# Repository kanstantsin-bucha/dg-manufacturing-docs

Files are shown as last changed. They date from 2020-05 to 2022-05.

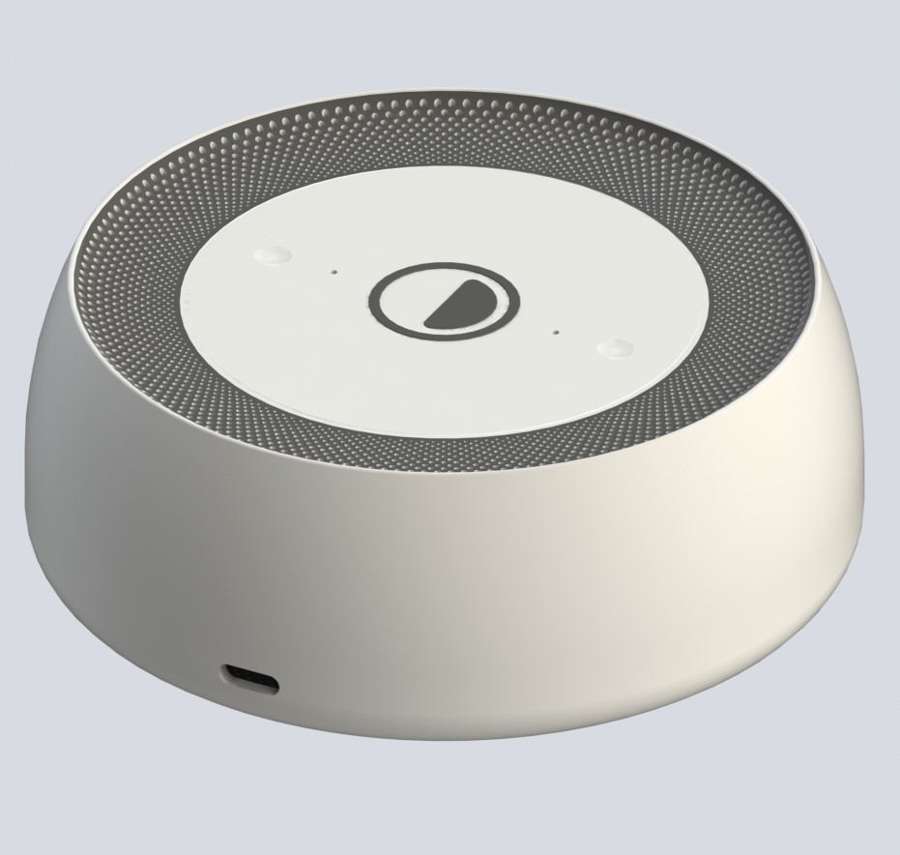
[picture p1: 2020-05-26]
housing/enclosure/DAir-Lily/Preview/2_.jpg

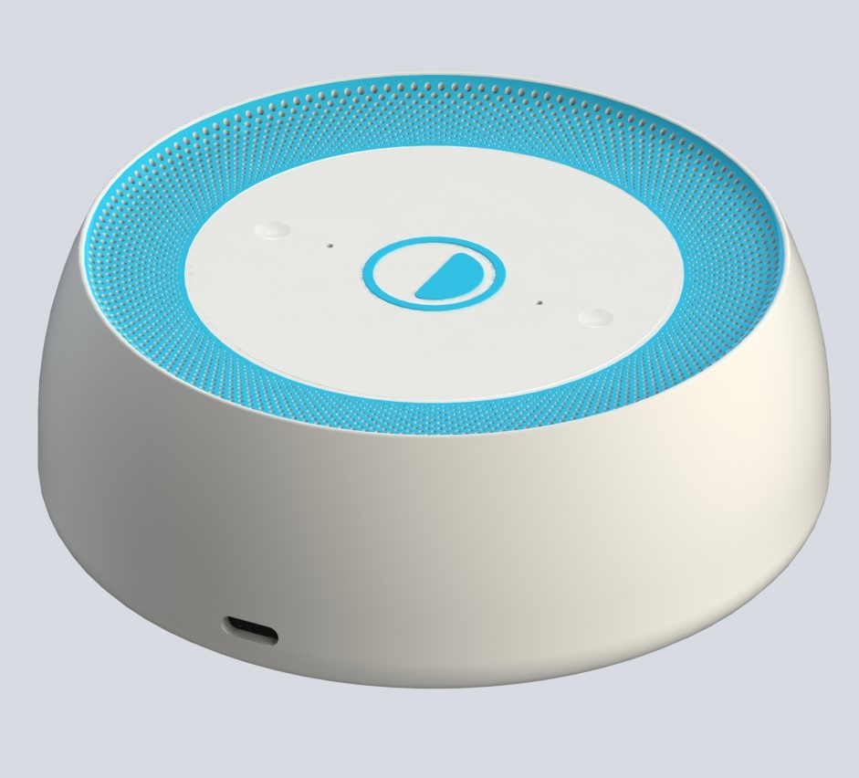
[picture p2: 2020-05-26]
housing/enclosure/DAir-Lily/Preview/1_.jpg

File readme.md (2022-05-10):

## Commit style 

123 - Title of the task

* Description of change that were introduced in commit 
* Same here

## Naming Style

* We use only characters from base table (english) to name the files and directories in repo

----

# This is repo for docs related to manufacturing the Detecta Group first smart portable gas detector

# MVP

* Currrent MVP is D-Air Aster in the chinese housing. The latest board version is 0.0.0.4

* We stop our development of the housing because it is too cost inaffective.
We should use housing from the 3-rd party.

# Table of directories

## electric - all related to circuit part of the Thing

*  circuit - Schematic of electric part of the Thing

## housing - all related to development of the housing

> D-Fire (Detecta Plug-in) - model housing with Plug-in

> D-Fire (Detecta microUSB) - model housing with microUSB

> D-Fire (OKW) - model housing OKW

> Model - models of the housing and parts made in Solidworks

> Models for 3D printing - models STL and STEP formats

> Doc - Drawings

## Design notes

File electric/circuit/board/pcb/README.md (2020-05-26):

# Versioning:

X.Y.Z

----

* Letter X means type of housing:

0 - portable housing with charger function

1 - OKW housing

2 - Detecta housing with/without plug or usb

----

* Letter Y means version of circuit:

1 - old version for portable housing with charger function

2 - current circuit version

3,4,5,... - future circuits

----

* Letter Z means different fixes. For example overlay fixing or litle other components layout

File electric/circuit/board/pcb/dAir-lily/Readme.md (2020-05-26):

# Versions

- [x] Pretest

# Notes

main-bottom --- test layout where all main components are on the bottom pcb, buttons and leds on the top pcb, ME2-CO is looking down

main-top --- test lay

out where all components are on the top pcb, on the bottom pcb only power supply components, ME2-CO is looking up

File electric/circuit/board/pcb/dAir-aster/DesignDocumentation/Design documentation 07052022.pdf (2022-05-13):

Формат А4 Инв.№подл. Взам.инв.№ Инв.№дубл. Подп. и дата Подп. и дата Спарв. № Перв. примен.

Н.контр. | Фамилия
Утв. | Фаимлия
| Лист
Разраб. | Фамилия | | | Спецификация | Лит. | Лист | Листов
| | Пров. | Фамилия
| | Т.контр.
Изм. | № докум. | Подпись | Дата Формат Зона Поз. | Обозначение | Наименование | Кол. | Приме-

## чание

Документация

А | 1 | 2 Устройство хххххх

## АБВГД.3.003.000

А3 | АБВГД.3.003.000 СБ | Сборочный чертёж
А2 | АБВГД.3.003.000 Э3 | Схема электрическая
| | принципиальная
А4 | АБВГД.3.003.000 ПЭ | Перечень элементов
А4 | ТУ BY 000000000.003-2021-ТУ | Технические условия
А4 | АБВГД.3.003.000 РЭ | Руководство по эксплуатации

Сборочные единицы

А2 | АБВГД.3.003.101 СБ | Плата

Детали

А3 | 2 | АБВГД.3.003.001 | Основание | 1
А3 | 3 | АБВГД.3.003.002 | Крышка | 1

1

Формат А4 Инв.№подл. Взам.инв.№ Инв.№дубл. Подп. и дата Подп. и дата Спарв. № Перв. примен. | Формат Зона | Поз. | Обозначение | Наименование | Кол. | Приме-

чание

Копировал

Изм.Лист | № докум. | Подпись | Дата

Стр.

## 2 АБВГД.3.003.000

Стандартные изделия

4 | Винт М2×5 | 4

Формат А2 Инв.№подл. Взам.инв.№ Инв.№дубл. Подп. и дата Подп. и дата Спарв. № Перв. примен.

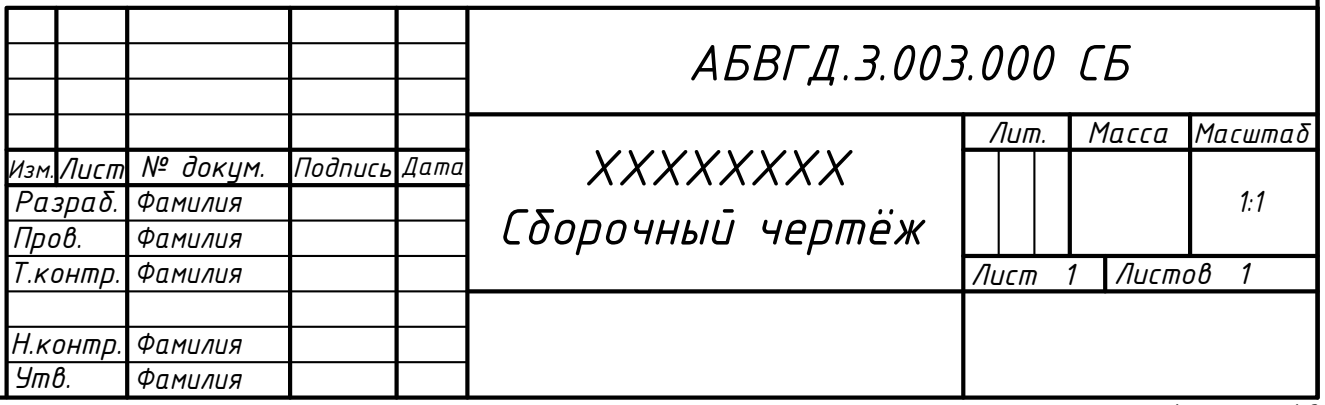
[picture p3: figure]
Лист Разраб. Пров.; № докум.; Листов 1; Лит.; Лист 1; Масса; Изм.; Подпись; Дата; Масштаб; АБВГД.3.003.000 СБ; XXXXXXXX Сборочный чертёж

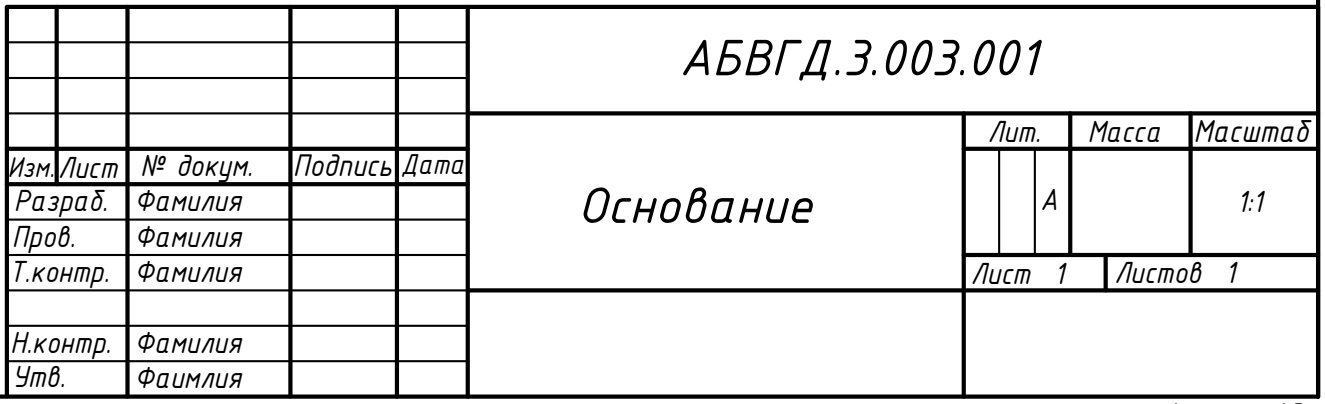
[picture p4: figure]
Лист Разраб. Пров.; № докум.; Листов 1; Лит.; Лист 1; Масса; Изм.; Подпись; Дата; Масштаб А; Фамилия; Фаимлия; Основание; АБВГД.3.003.001

Формат А3

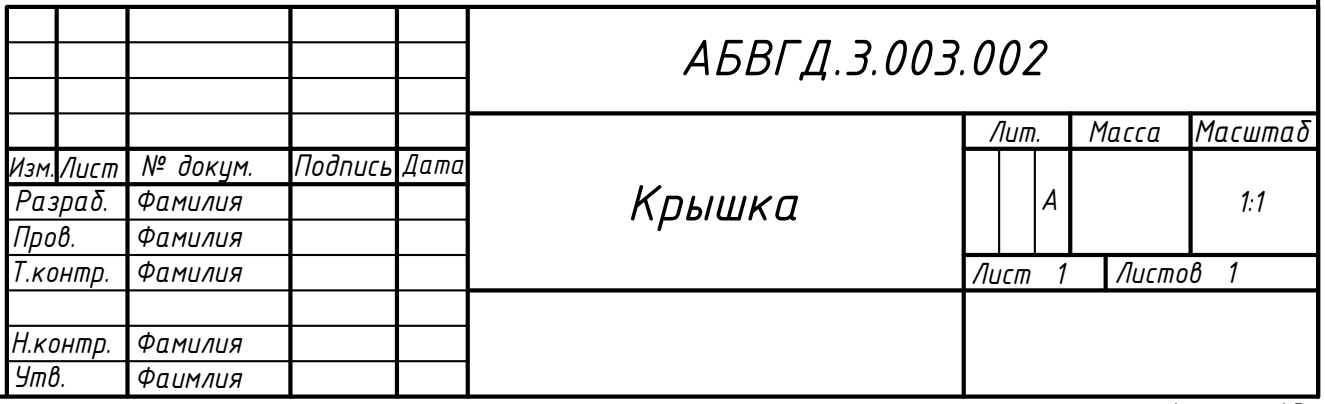
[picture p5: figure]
Лист Разраб. Пров.; № докум.; Листов 1; Лит.; Лист 1; Масса; Изм.; Подпись; Дата; Масштаб А; Фамилия; Фаимлия; Крышка; АБВГД.3.003.002

Формат А3

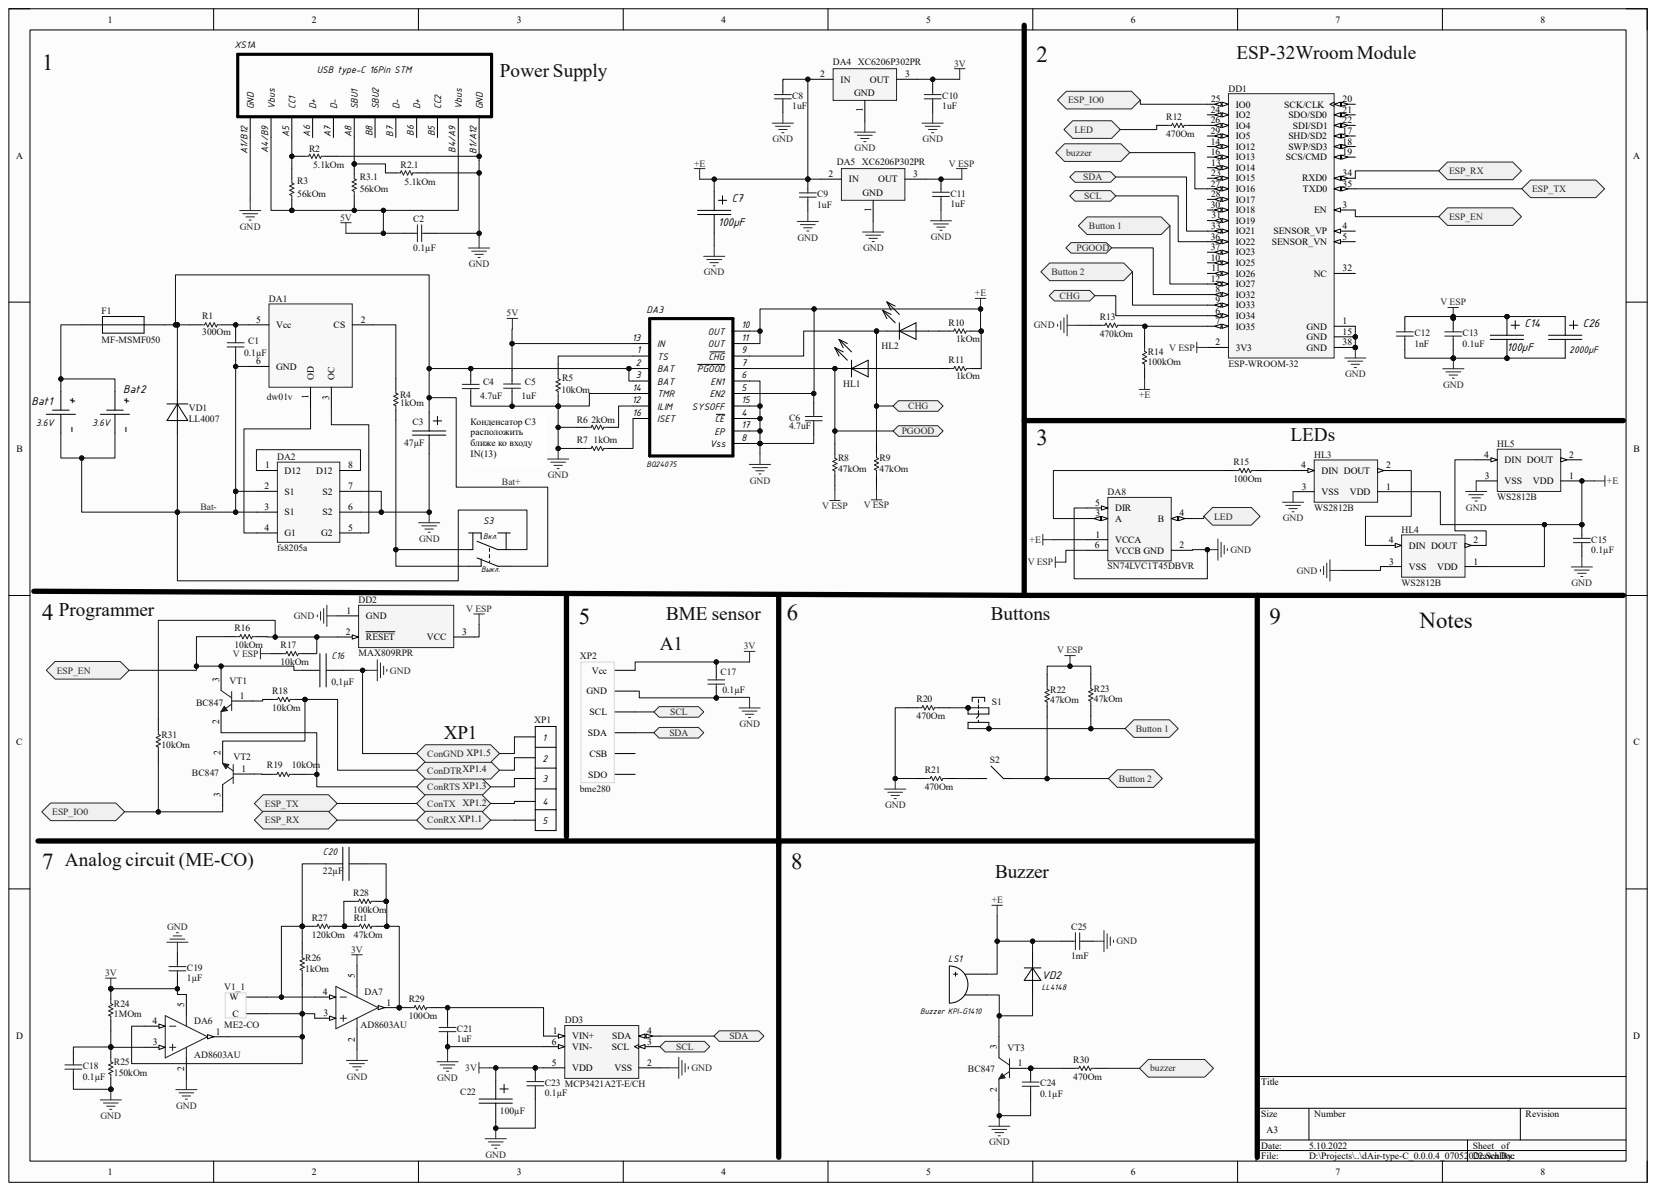
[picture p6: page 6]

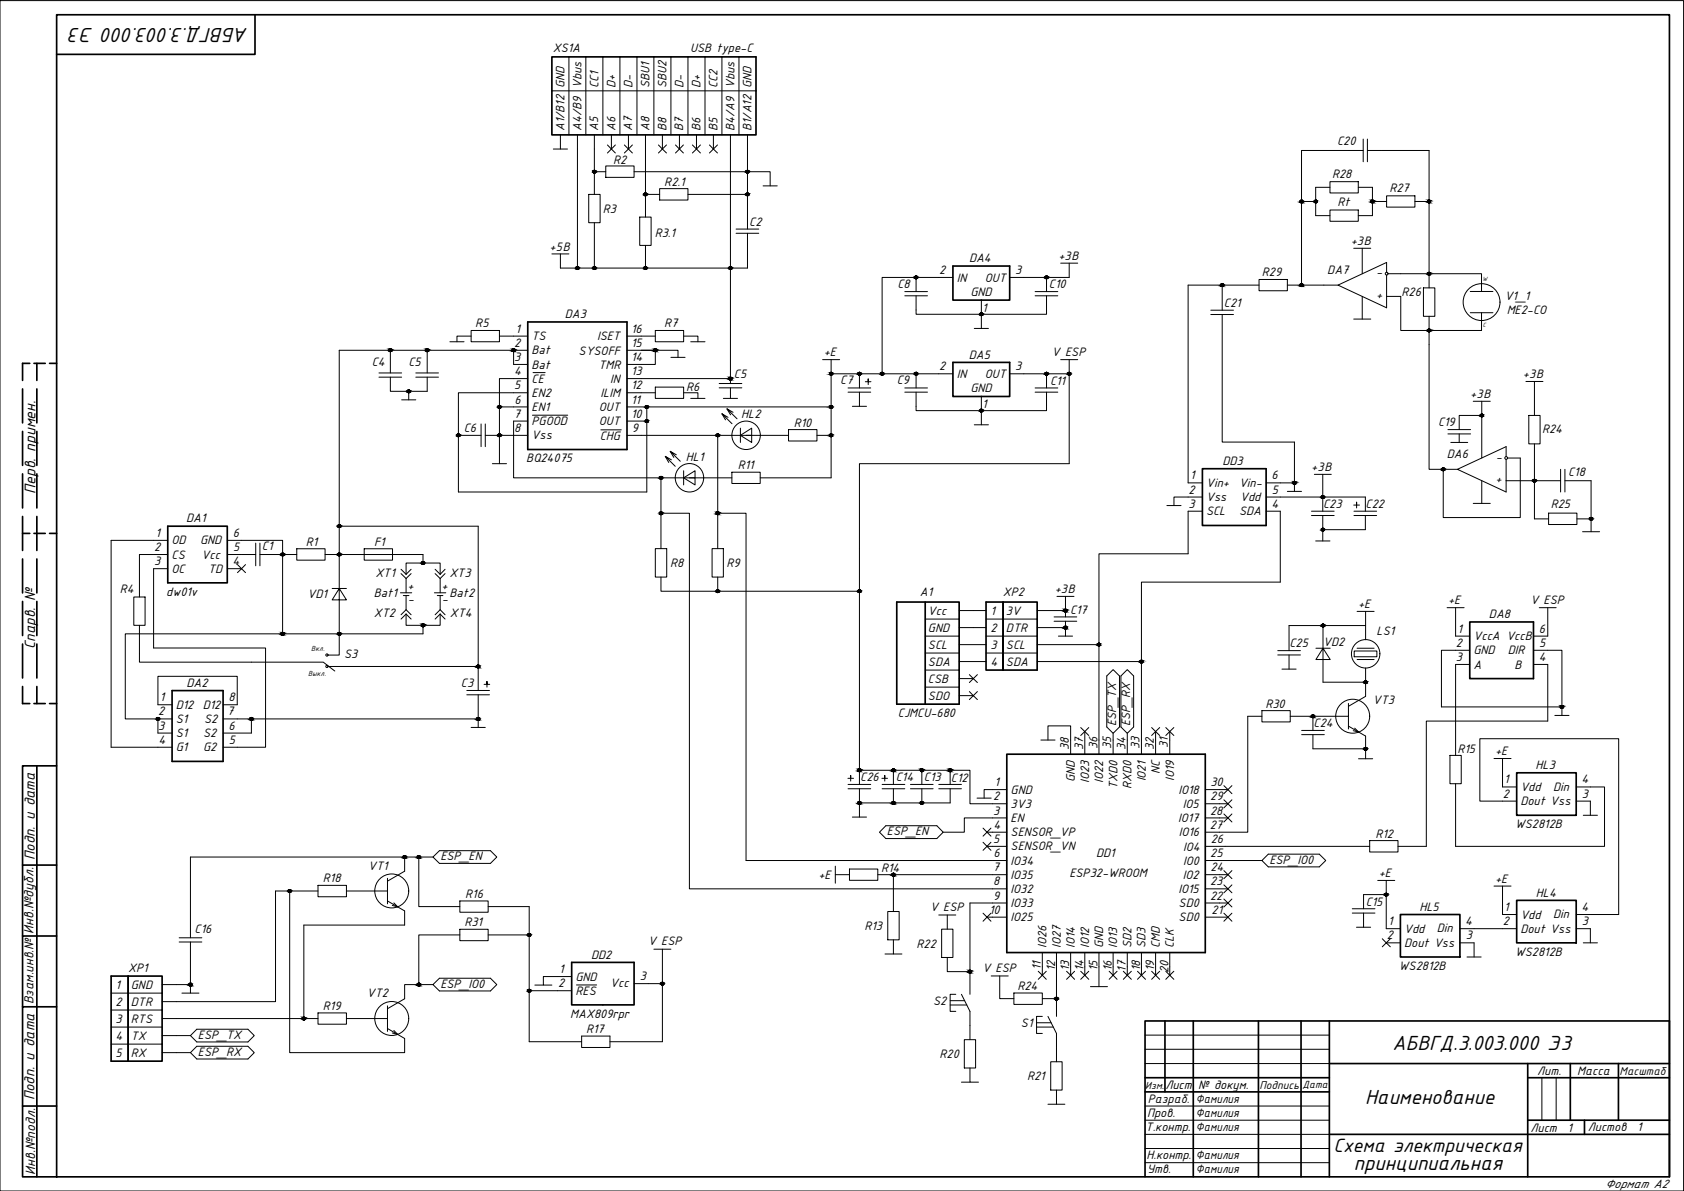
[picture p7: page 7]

Формат А2 Инв.№подл. Взам.инв.№ Инв.№дубл. Подп. и дата Подп. и дата Спарв. № Перв. примен.

IO18 IO¹⁹NC IO2¹ TXD⁰ RXD⁰ GND IO23 IO22

2 | DTR
3 | RTS
4 | TX

Формат А4 Инв.№подл. Взам.инв.№ Инв.№дубл. Подп. и дата Подп. и дата Спарв. № Перв. примен.

Наименование | Кол.
Изм. | Лист | № докум. | Подпись | Дата
| Разраб. | Фамилия | | | Перечень элементов | Лит. | Лист | Листов
| Пров. | | | | | 1 | | 3

Поз. обозна-

чение

## Примечание

## АБВГД.3.003.000 ПЭ

DA6,DA7

DA1 | 1

1

Микросхемы

Контроллер заряда АКБ DW01V | SOT23-6
DA2 | Транзисторная сборка FS8205A, 2-mosfet N-channel | 1 | TSSOP-8
DA3 | Контроллер заряда Li-ion АКБ BQ24075RGT | 1 | VQFN-16
| LDO регулятор напряжения XC6206P302PR 3В, 0.2А | | SOT89-3
| Операционный усилитель AD8603AU, rail-to-rail | | TSOT-5
| | 2
| | 2
DA8 | Преобразователь уровня SN74LVC1T45DBVR | 1 | SOT23-6
DD1 | Микроконтроллер ESP32-WROOM 38-pin | 1
DD2 | Супервизор MAX809RPR 2.62В | 1 | SOT-23
DD3 | АЦП MCP3421A2T-E/CH, 2.7-5.5В, 18 бит | 1 | SOT23-6

Резисторы

R1 | Резистор 300Ом±5% smd 0805 | 1
R2,R2.1 | Резистор 5,1кОм±5% smd 0805 | 2
R3,R3.1 | Резистор 56кОм±5% smd 0805 | 2
R4,R7 | Резистор 1кОм±5% smd 0805 | 2
R5 | Резистор 10кОм±5% smd 0805 | 1
R6 | Резистор 2кОм±5% smd 0805 | 1
R8,R9 | Резистор 47кОм±5% smd 0805 | 2
R10,R11 | Резистор 1кОм±5% smd 0805 | 2
R12 | Резистор 470Ом±5% smd 0805 | 1
A1 | Модуль CJMCU-680 (BME680) | 1
| Сборочные единицы
R13 | Резистор 470кОм±5% smd 0805 | 1

DA4,DA5

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

Наименование | Кол.

Поз. обозна-

чение

## Примечание

Изм.Лист | № докум. | Подпись | Дата
.3.003.000 ПЭ | Стр. АБВГД 2
| Конденсаторы
С1,С2 | Керам. чип конденсатор 0,1мкФ±10% - 16В smd 0805 | 2 | X5R или X7R
С3 | Конденсатор танталовый 47мкФ±10% - 10В тип B | 1
С4,С6 | Керам. чип конденсатор 4,7мкФ±10% - 16В smd 0805 | 2 | X5R или X7R
С5 | Керам. чип конденсатор 1мкФ±10% - 16В smd 0805 | 1 | X5R или X7R
С7 | Конденсатор танталовый 100мкФ±10% - 16В тип B | 1
С8-С11 | Керам. чип конденсатор 1мкФ±10% - 16В smd 0805 | 4 | X5R или X7R
С12 | Керам. чип конденсатор 1нФ±10% - 10В smd 0805 | 1 | X5R или X7R
С13 | Керам. чип конденсатор 0,1мкФ±10% - 16В smd 0805 | 1 | X5R или X7R
С14 | Конденсатор танталовый 100мкФ±10% - 16В тип B | 1
С15 | Керам. чип конденсатор 0,1мкФ±10% - 16В smd 0805 | 1 | X5R или X7R
С16 | Керам. чип конденсатор 0,1мкФ±10% - 10В smd 0805 | 1 | X5R или X7R
С17,С18 | Керам. чип конденсатор 0,1мкФ±10% - 16В smd 0805 | 2 | X5R или X7R
С19 | Керам. чип конденсатор 1мкФ±10% - 10В smd 0805 | 1 | X5R или X7R
С20 | Керам. чип конденсатор 22мкФ±10% - 10В smd 0805 | 1 | X5R или X7R
R14 | Резистор 100кОм±5% smd 0805 | 1
R15 | Резистор 100Ом±5% smd 0805 | 1
R16-R19 | Резистор 10кОм±5% smd 0805 | 4
R20,R21 | Резистор 470Ом±5% smd 0805 | 2
R22,R23 | Резистор 47кОм±5% smd 0805 | 2
R24 | Резистор 1МОм±5% smd 0805 | 1
R25 | Резистор 150кОм±5% smd 0805 | 1
R26 | Резистор 1кОм±5% smd 0805 | 1
R27 | Резистор 120кОм±5% smd 0805 | 1
R28 | Резистор 100кОм±5% smd 0805 | 1
R29 | Резистор 100Ом±5% smd 0805 | 1
R30 | Резистор 470Ом±5% smd 0805 | 1
R31 | Резистор 10кОм±5% smd 0805 | 1
Rt | Резистор 47кОм±5% smd 0805 | 1

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

Наименование | Кол.

Поз. обозна-

чение

## Примечание

Изм.Лист | № докум. | Подпись | Дата
.3.003.000 ПЭ | Стр. АБВГД 3
| Транзисторы
VT1-VT3 | Транзистор BC847C | 3 | NPN, SOT-23
| Диоды
VD1 | Диод выпрямительный LL4007 | 1 | MELF/ DO-213AB
VD2 | Диод выпрямительный LL4148 | 1 | miniMELF/ SOD-80
HL1,HL2 | Светодиод GNL-1206SRC SMD | 2
HL3-HL5 | RGB cветодиод WS2812B | 3
| Разъёмы и держатели
XP1 | Линейка штыревая PLS-5 (DS1021-1×5) | 1 | 5 конт., шаг 2.54мм
XP2 | Линейка штыревая PLS-4 (DS1021-1×4) | 1 | 4 конт., шаг 2.54мм
XS1A | Разъём USB Type-C-31-M-12 | 1
XT1-XT4 | Держатель АКБ 18650 KEYS54 (KLS5-54T) | 4
С21 | Керам. чип конденсатор 1мкФ±10% - 16В smd 0805 | 1 | X5R или X7R
С22 | Конденсатор танталовый 100мкФ±10% - 16В тип B | 1
С23,С24 | Керам. чип конденсатор 0,1мкФ±10% - 16В smd 0805 | 2 | X5R или X7R
С25 | Керам. чип конденсатор 1мФ±10% - 10В smd 0805 | 1 | X5R или X7R
С26 | Конденсатор электролит. 2000мкФ±10% - 10В | 1 | ∅13×20×5мм
| Прочее
LS1 | Зуммер пьезоэлектрический KPI-G1410 | 1
F1 | Предохранитель самовосст. MF-MSMF075, 0.75A | 1 | SMD 1812
V1_1 | Газовый сенсор МЕ2-СО | 1
Bat1,Bat2 | Li-ion АКБ NCR18650, 3200mAH | 2
S1 | Кнопка тактовая KLS-TS6604-7.0 или IT1102WB | 1 | прямая, h=7мм, SMD
S2 | Кнопка тактовая KLS-TS6606-8.0 или IT1102HC, или | 1 | угловая, h=8мм
| TS-A3PV, или TC-0206, или IT-1102NC
S3 | Кнопочный переключатель 58LHTHRA | 1

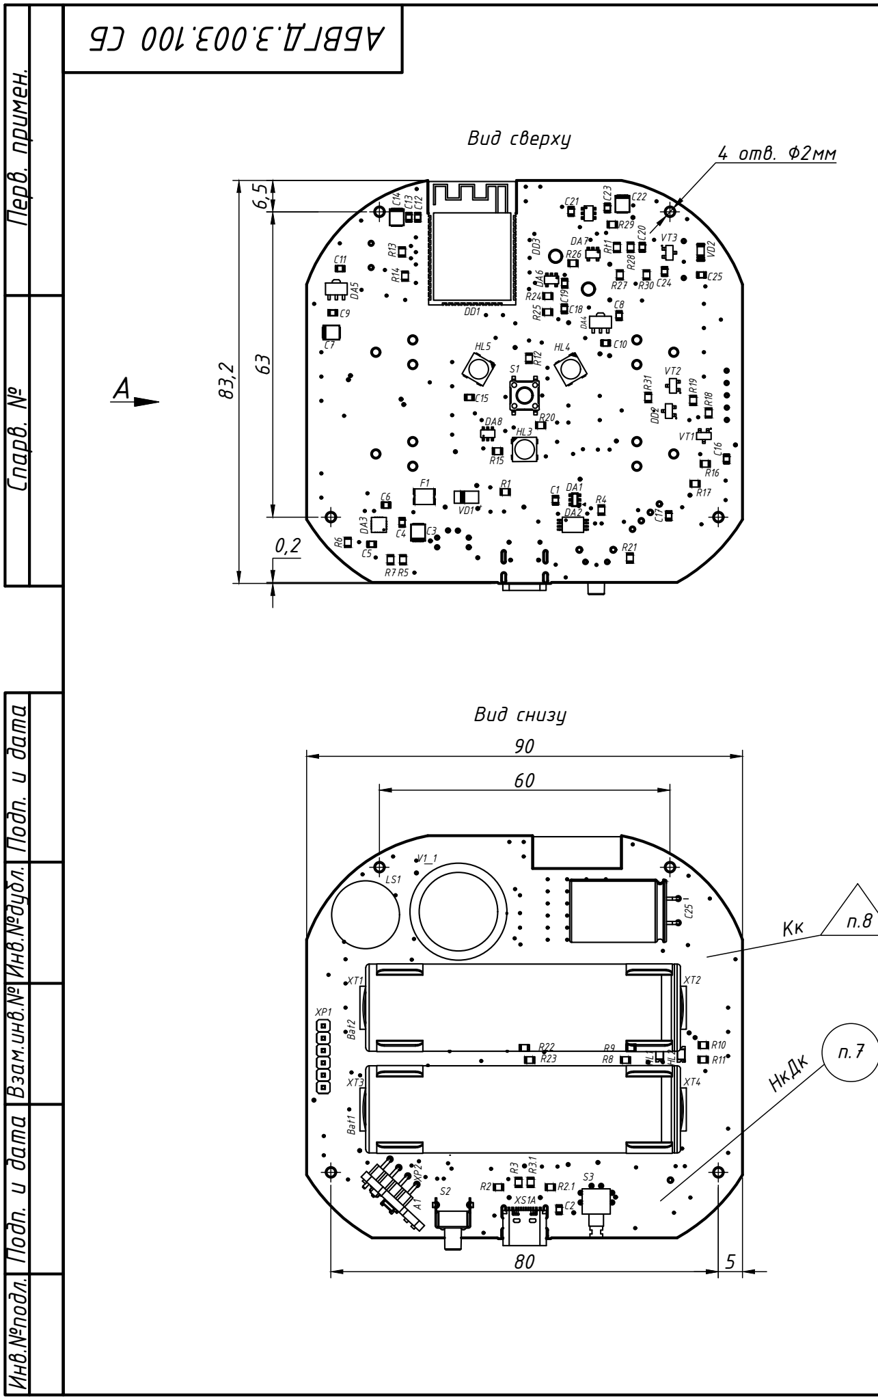
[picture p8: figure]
C¹⁶ Rt1; F1 DA³; DA7 DA⁶; DD² DD³; C4 DA⁵; DA⁴; VD²; Вид сверху 83,2 0,2 ⁶,5 63; C25 Bat1; Вид снизу; НкДк п.7; 4 отв. ∅2мм; C1 Bat2
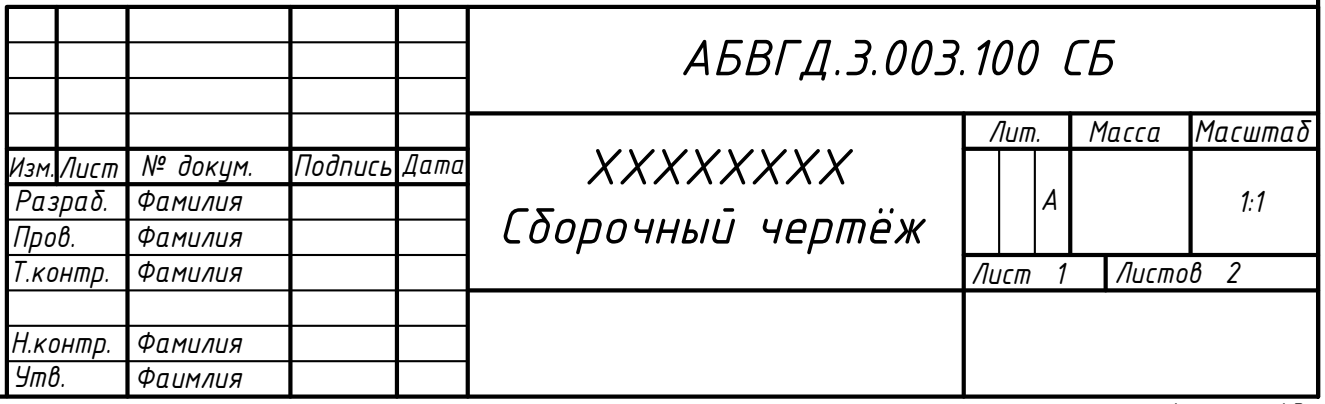
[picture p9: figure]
Лист Разраб. Пров.; № докум.; Листов 2; Лит.; Лист 1; Масса; Изм.; Подпись; Дата; Масштаб; Фамилия; Фаимлия; XXXXXXXX Сборочный чертёж; АБВГД.3.003.100 СБ

Формат А3

1. Размеры для справок. 2. Монтаж РЭ вести согласно чертежа, ГОСТ 29137.
3. Пайку выводов ЭРЭ производить припоем ТЗА ПОС-61М ГОСТ 21931.
4. Маркировка держателелей АКБ XT1-XT4 показана условно. 5. Монтаж на плату элементов поз. 48-51 производить после промывки и просушки

печатного узла. 5. Высота выступающих концов выводов должна быть в пределах от 2 до 2,5мм. 6. Запрограммировать устройство через программатор xxxxxxxx, подклюив к разъёму XP1,

файлом прошивки "xxxxxxxxxx" программы микроконтроллера XXXX.X.XXXX.XXX.
7. Маркировать порядковый заводской номер печатного узла и год изготовления. 8. Клеймить знак ОТК. 9. После сборки и регулировки печатный узел со стороны элемента DD1 покрыть лаком

УР-231 бесцветным. Элементы HL3,HL4,HL5, S1 от покрытия предохранить.

Установка С25
(2:1)

макс. 3мм

п.3

0,1 | 0,1
| 0,1

Установка R1-R31, Rt, C1-C25 (5:1)

# макс. 20,5мм 14 А

2:1

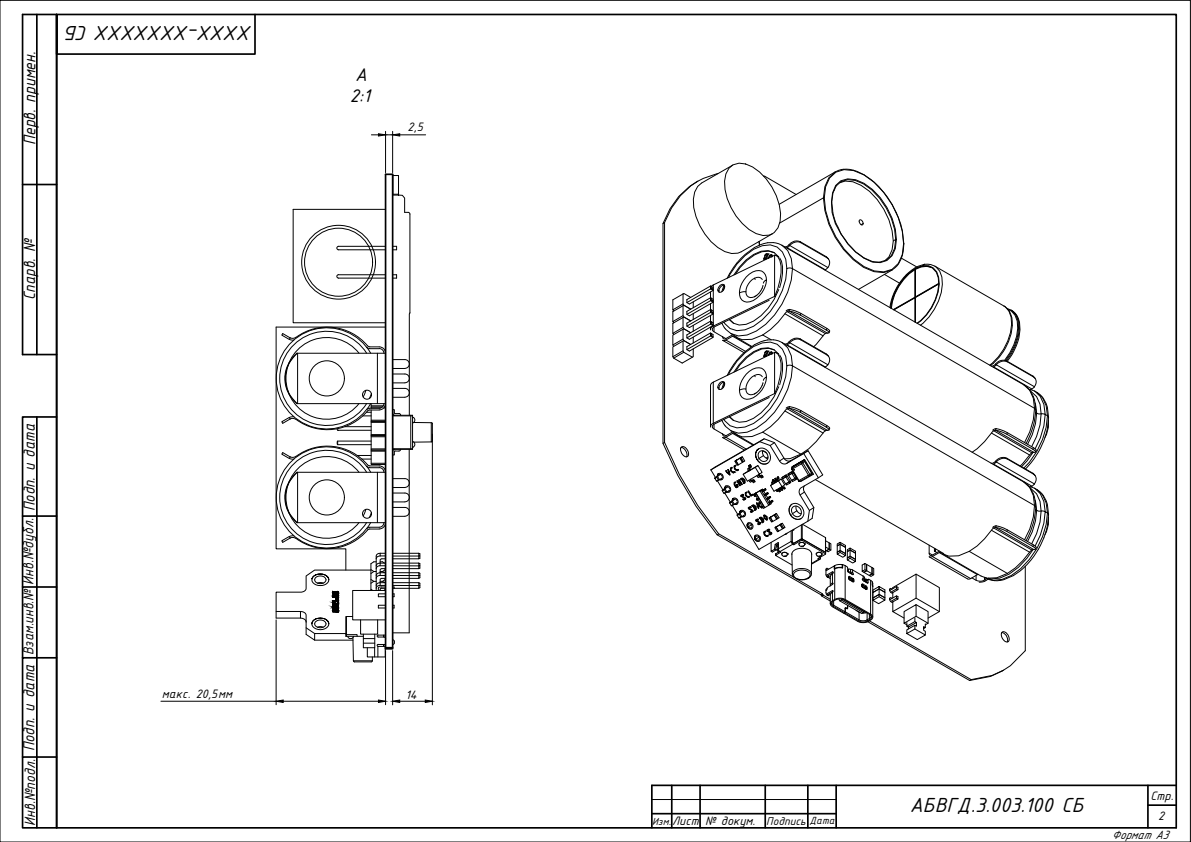
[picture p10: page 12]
Формат А3; Изм.Лист; № докум.; Подпись; Дата

Стр. 2 АБВГД.3.003.100 СБ

Формат А4 Инв.№подл. Взам.инв.№ Инв.№дубл. Подп. и дата Подп. и дата Спарв. № Перв. примен. | Формат Зона | Поз. | Обозначение | Наименование | Кол. | Приме-

чание

Изм. | Лист | № докум. | Подпись | Дата
Разраб. | Фамилия | | | Устройство хххххх Плата | Лит. | Лист | Листов
| | Пров. | Фамилия | | | | | А | 1 | 4

Документация

А3 | АБВГД.3.003.100 СБ | Сборочный чертёж

## АБВГД.3.003.100

Фаимлия

*) | АБВГД.0.000.000 | Исходный текст | -*) DVD-R
А4 | АБВГД.0.000.000 | Исходный текст | Размножить по особому указанию

Детали

*) | АБВГД.0.000.000 | Программа микроконтроллера | -*) DVD-R
А4 | АБВГД.0.000.000 | | особому указанию Размножить по Программа микроконтроллера
*) | АБВГД.0.000.000 | Файл данных платы | -*) DVD-R
А4 | АБВГД.0.000.000 | | особому указанию Размножить по Файл данных платы
А3 | 1 | Плата печатная | 1
| Прочие изделия
2 | Зуммер KPI-G1410 | 1 | LS1
3 | Предохранитель MF-MSMF075 | 1 | F1
4 | Газовый сенсор МЕ2-СО | 1 | V1_1
5 | CJMCU-680 (BME680) | 1 | A1
6 | Li-ion АКБ NCR18650 | 2 | Bat1,BAt2

АБВГД.3.003.101

Формат А4 Инв.№подл. Взам.инв.№ Инв.№дубл. Подп. и дата Подп. и дата Спарв. № Перв. примен. | Формат Зона | Поз. | Обозначение | Наименование | Кол. | Приме-

чание

Изм.Лист | № докум. | Подпись | Дата

Стр.

2

7 | Кнопка KLS-TS6604-7.0 | 1 | S1
| или IT1102WB
8 | Кнопка KLS-TS6606-8.0 | 1 | S2
| или IT1102HC, или TS-A3PV,
| или TC-0206, или IT-1102NC
9 | Кнопочный переключатель | 1
| 58LHTHRA | | S3

## АБВГД.3.003.100

| Микросхемы
10 | DW01V | 1 | DA1
11 | FS8205A | 1 | DA2
12 | BQ24075RGT | 1 | DA3
13 | XC6206P302PR | 2 | DA4,DA5
14 | AD8603AU | 2 | DA6,DA7
15 | SN74LVC1T45DBVR | 1 | DA8
16 | ESP32-WROOM 38-pin | 1 | DD1
17 | MAX809RPR | 1 | DD2
18 | MCP3421A2T-E/CH | 1 | D3
| Резисторы
19 | 300Ом±5% smd 0805 | 1 | R1
20 | 5,1кОм±5% smd 0805 | 2 | R2,R2.1
21 | 56кОм±5% smd 0805 | 2 | R3,R3.1
22 | 1кОм±5% smd 0805 | | R4,R7,R10, R11,R26 5
23 | 10кОм±5% smd 0805 | 6 | R5,R16-R19 R31
24 | 2кОм±5% smd 0805 | 1 | R6
25 | 47кОм±5% smd 0805 | 5 | R8,R9,R22, R23,Rt
26 | 470Ом±5% smd 0805 | 4 | R12,R20,R21, R30

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

чание

Изм.Лист | № докум. | Подпись | Дата

Стр.

3

| Конденсаторы | | C17,С18,С23,С24
33 | 0,1мкФ±10%-16В smd 0805 X7R | 8 | C1,C2,C13,С15
34 | 0,1мкФ±10%-10В smd 0805 X7R | 1 | С16
35 | 47мкФ±10%-10В тип B | 1 | С3
36 | 4,7мкФ±10%-16В smd 0805 X7R | 2 | C4,C6
37 | 1мкФ±10%-16В smd 0805 X7R | 7 | C5,C8-C11, C19,C21
38 | 100мкФ±10%-16В тип B | 3 | C7,C14,C22
39 | 1нФ±10%-10В smd 0805 X7R | 1 | С12
40 | 22мкФ±10%-10В smd 0805 X7R | 1 | С20
41 | 1мФ±10% - 10В smd 0805 X7R | 1 | С25
42 | К50-35-10В-2000мкФ 13×20мм | 1 | С26

## АБВГД.3.003.100

| Транзисторы
43 | BC847C | 3 | VT1-VT3
| Диоды
44 | LL4007 MELF/ DO-213AB | 1 | VD1
45 | LL4148 miniMELF/ SOD-80 | 2 | VD2
46 | GNL-1206SRC SMD | 2 | HL1,HL2
47 | RGB cветодиод WS2812B | 3 | HL3-HL5
27 | 470кОм±5% smd 0805 | 1 | R13
28 | 100кОм±5% smd 0805 | 2 | R14,R28
29 | 100Ом±5% smd 0805 | 2 | R15,R29
30 | 1МОм±5% smd 0805 | 1 | R24
31 | 150кОм±5% smd 0805 | 1 | R25
32 | 20кОм±5% smd 0805 | 1 | R27

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

чание

Изм.Лист | № докум. | Подпись | Дата

Стр.

4

| Разъёмы и держатели
48 | PLS-5 (DS1021-1×5) | 1 | XP1
49 | PLS-4 (DS1021-1×4) | 1 | XP2
50 | Разъём USB Type-C-31-M-12 | 1 | XS1A
51 | KEYS54 (KLS5-54T) | 4 | XT1-XT4

## АБВГД.3.003.100

Электрорадиоэлементы, устанавливаемые при монтаже, смотри

АБВГД.3.003.000 ПЭ

Ra12,5( )

60

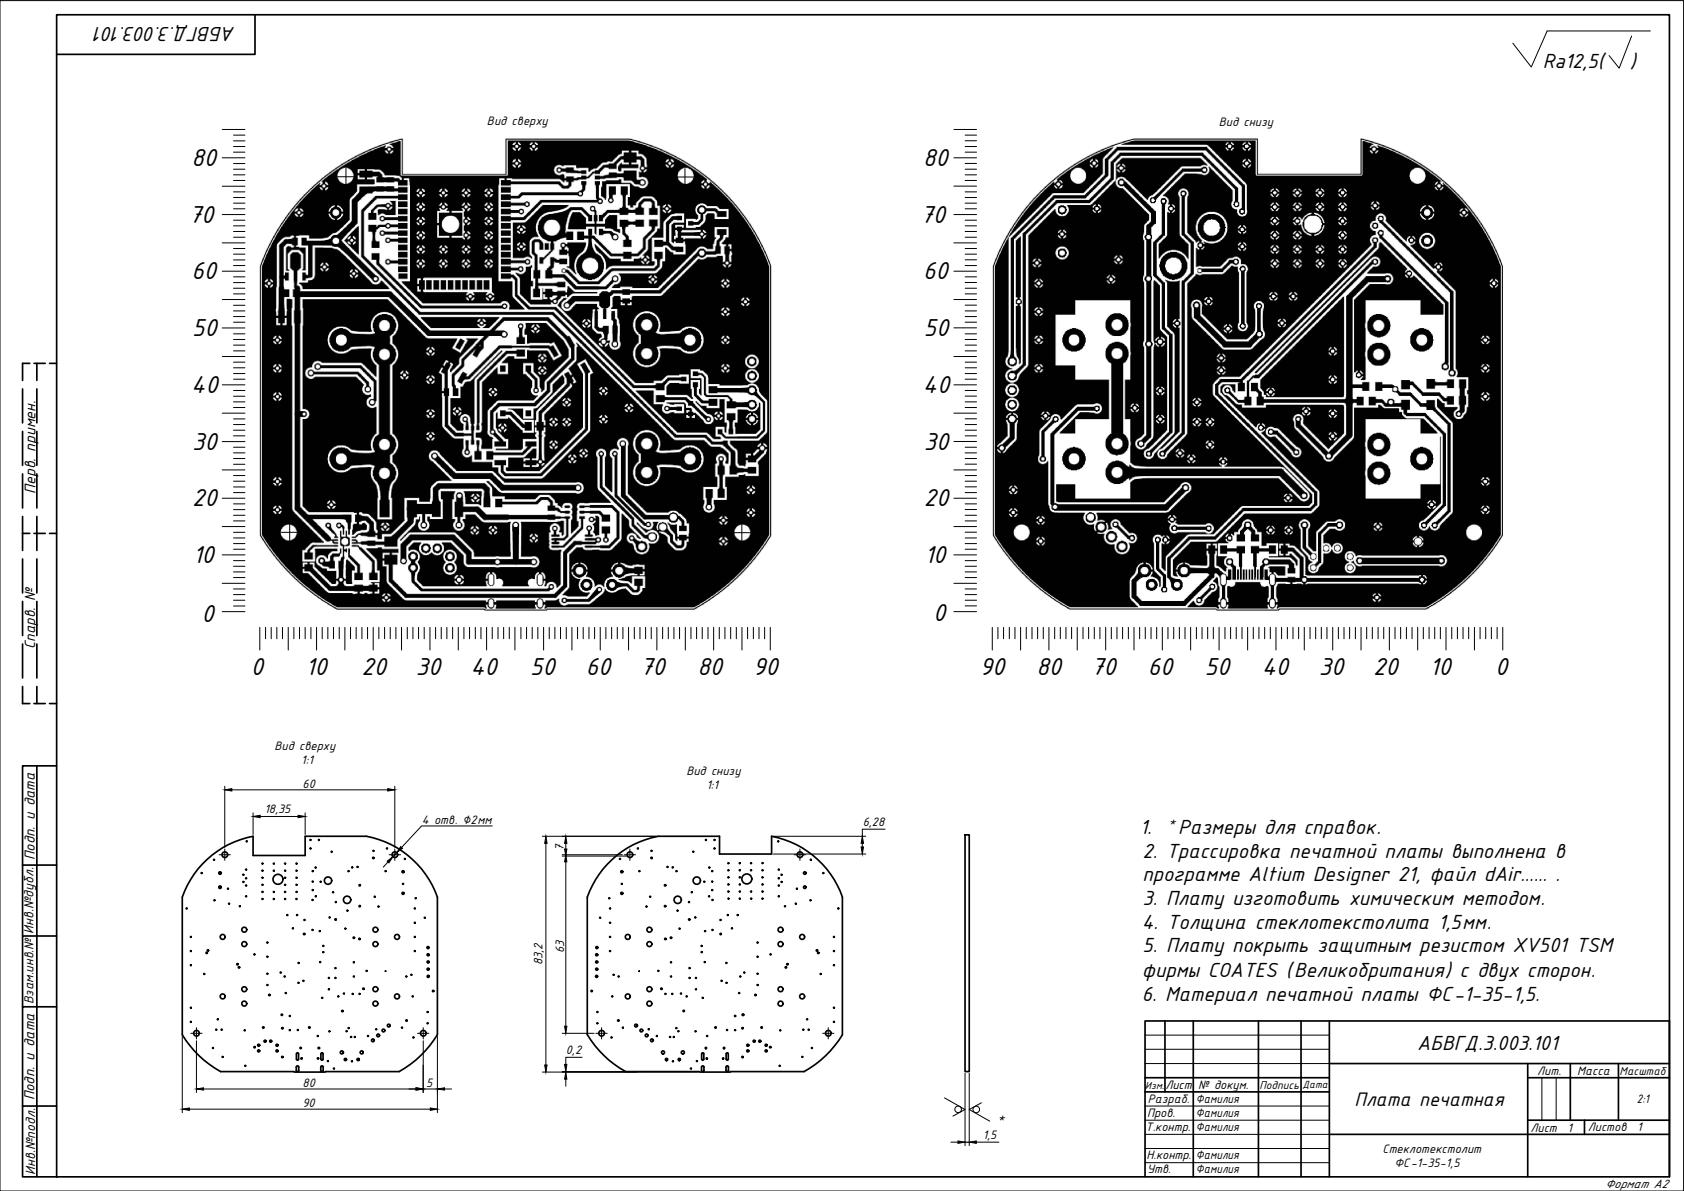
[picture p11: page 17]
Лист Разраб. Пров.; № докум.; Листов 1; Лит.; Лист 1; Масса; Изм.; Подпись; Дата; Масштаб; АБВГД.3.003.101; Плата печатная; Стеклотекстолит ФС-1-35-1,5; Вид сверху 1:1; Вид снизу 1:1; Вид сверху; Вид снизу; 4 отв. ∅2мм

Формат А2 Инв.№подл. Взам.инв.№ Инв.№дубл. Подп. и дата Подп. и дата Спарв. № Перв. примен.

1. Размеры для справок. 2. Трассировка печатной платы выполнена в

программе Altium Designer 21, файл dAir...... .
3. Плату изготовить химическим методом. 4. Толщина стеклотекстолита 1,5мм. 5. Плату покрыть защитным резистом XV501 TSM

фирмы COATES (Великобритания) с двух сторон. 6. Материал печатной платы ФС-1-35-1,5.

Т.контр Инв. № подп. Подп. и дата Взам. инв. № Инв. № дубл. Подп. и дата Справ. № Перв. примен.

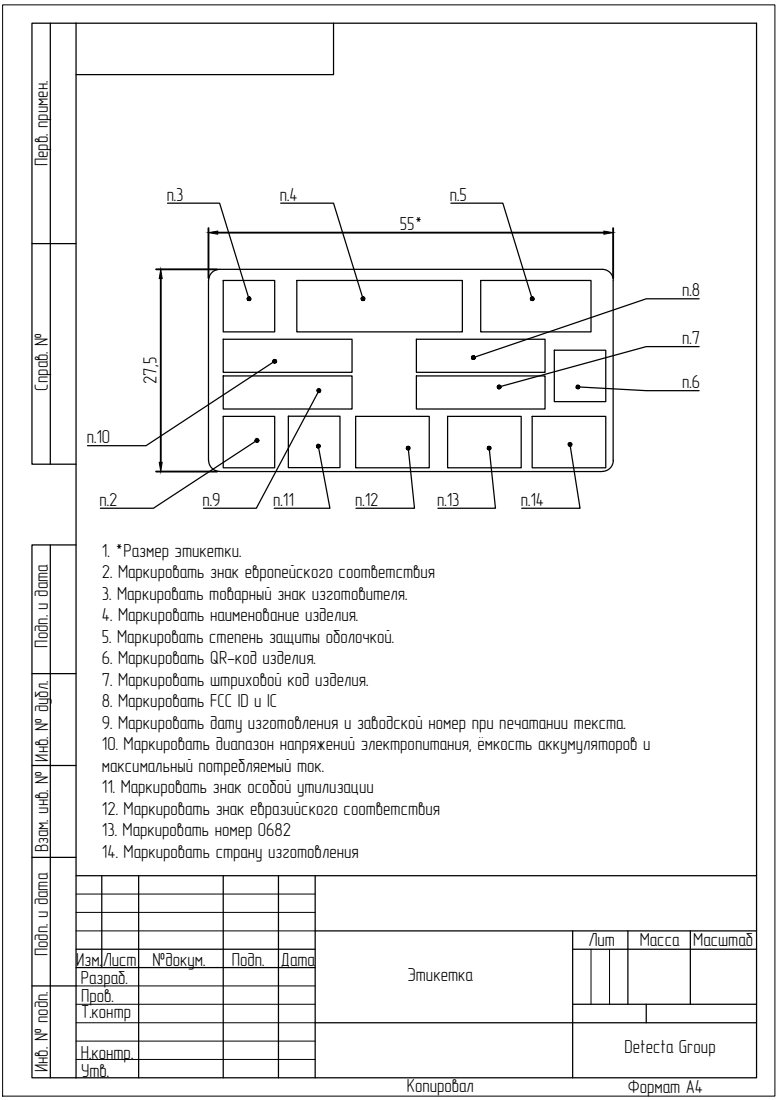
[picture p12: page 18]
Н.контр. Утв.; Лит; Масса; Масштаб; Detecta Group; Этикетка; Копировал; Формат А4

1. *Размер этикетки. 2. Маркировать знак европейского соответствия

3. Маркировать товарный знак изготовителя. 4. Маркировать наименование изделия. 5. Маркировать степень защиты оболочкой. 6. Маркировать QR-код изделия. 7. Маркировать штриховой код изделия. 8. Маркировать FCC ID и IC

9. Маркировать дату изготовления и заводской номер при печатании текста. 10. Маркировать диапазон напряжений электропитания, ёмкость аккумуляторов и

максимальный потребляемый ток. 11. Маркировать знак особой утилизации

12. Маркировать знак евразийского соответствия
13. Маркировать номер 0682
14. Маркировать страну изготовления

Изм. | Лист | №докум. | Подп. | Дата
Разраб. Пров.

Т.контр Инв. № подп. Подп. и дата Взам. инв. № Инв. № дубл. Подп. и дата Справ. № Перв. примен.

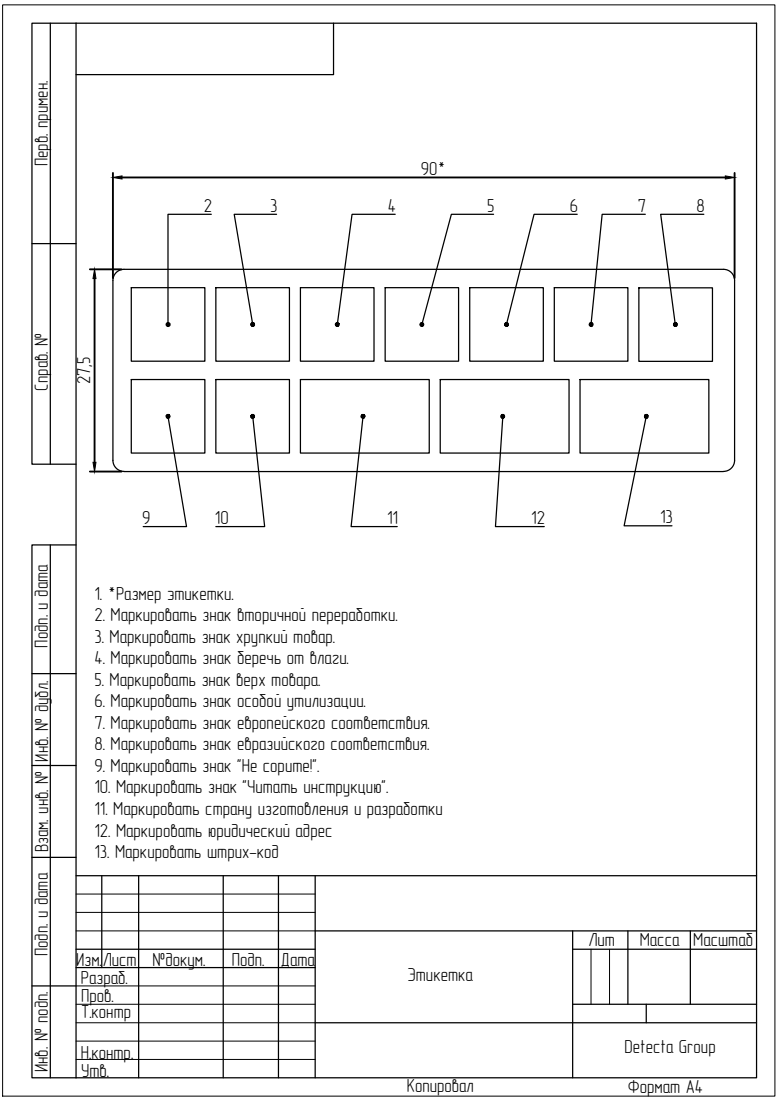
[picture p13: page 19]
Н.контр. Утв.; Лит; Масса; Масштаб; Detecta Group; Этикетка; Копировал; Формат А4

1. *Размер этикетки. 2. Маркировать знак вторичной переработки. 3. Маркировать знак хрупкий товар. 4. Маркировать знак беречь от влаги. 5. Маркировать знак верх товара. 6. Маркировать знак особой утилизации. 7. Маркировать знак европейского соответствия. 8. Маркировать знак евразийского соответствия. 9. Маркировать знак "Не сорите!".

10. Маркировать знак "Читать инструкцию".
11. Маркировать страну изготовления и разработки
12. Маркировать юридический адрес
13. Маркировать штрих-код

Изм. | Лист | №докум. | Подп. | Дата
Разраб. Пров.

### DAir-ASTER IP41

Input voltage: 5V± 5%
Input current: 300mA
Battery capacity: 2000mAh

12.11.2021

P/N: 89498299

FCC ID: HD5-HAQ
IC: 16938-HAQ

Made in
Republic of
Belarus

Desig ned by R epublic
of Belarus
Made in Republic of
Belarus

Detecta Group,
Masherova Str. 123,
210333 Minsk
Belarus 2020

### DAir-ASTER IP41

Входное питание: 5В± 5%

Ток потребления: 500мA
Ёмкость акку мулятора: 4400мАч
12.11.2021

P/N: 89498299

ИП 435-01-1Д

Сделано в
Республике
Белару сь

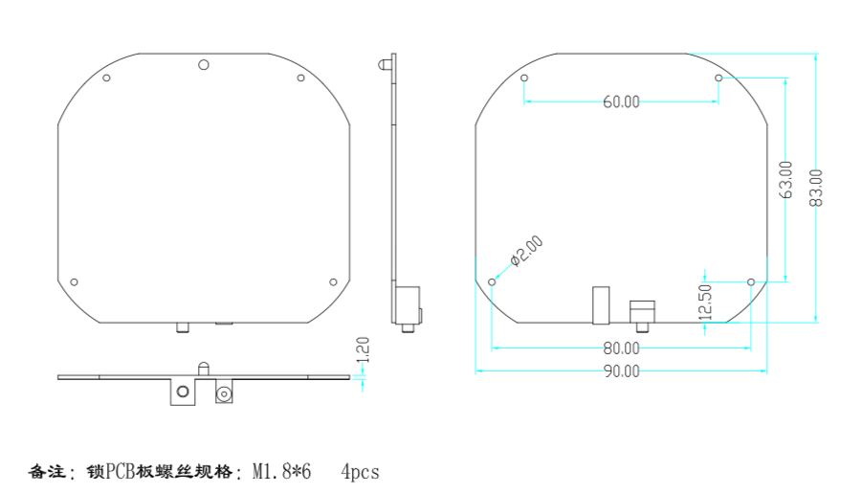
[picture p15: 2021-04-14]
electric/circuit/board/pcb/dAir-aster/DesignDocumentation/Board dimensions.jpg

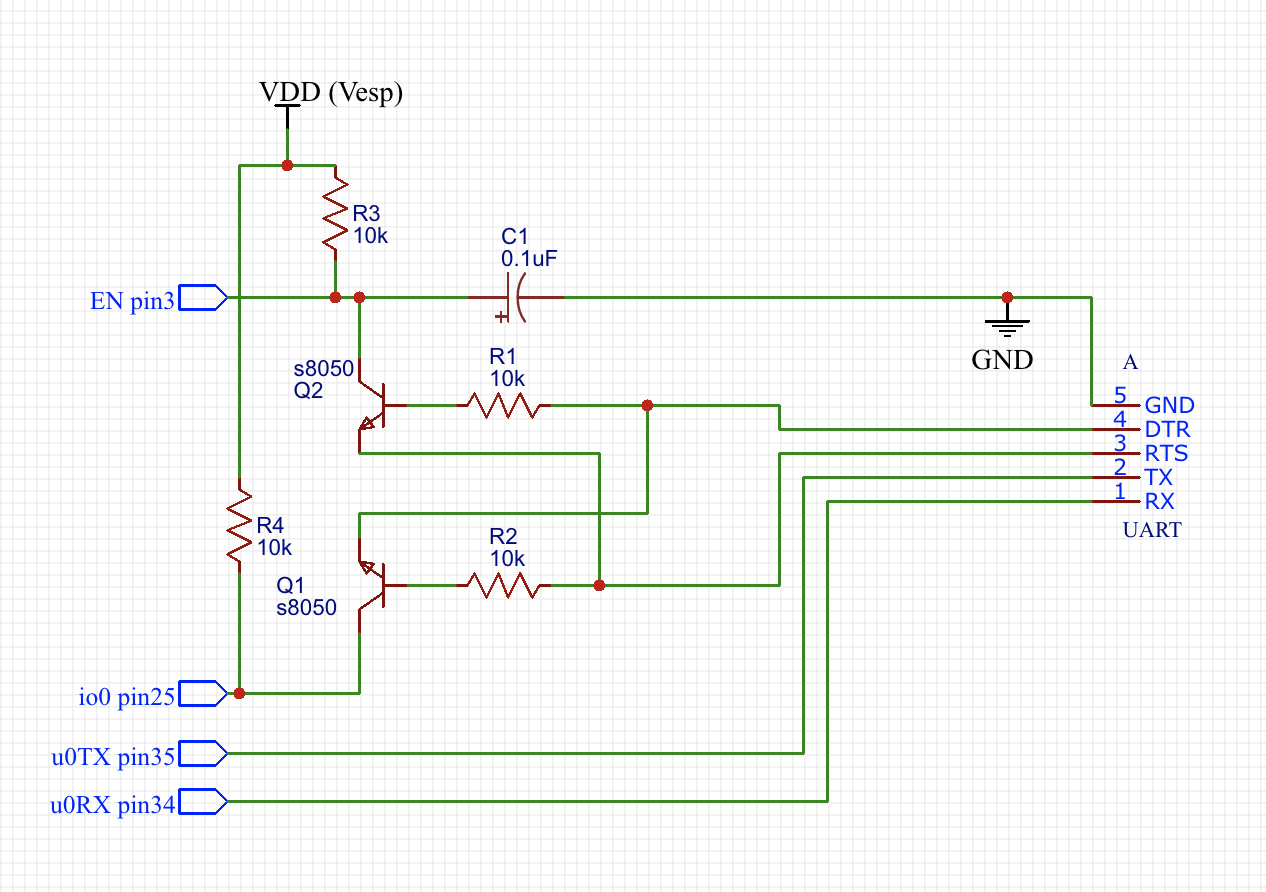
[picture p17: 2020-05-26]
electric/circuit/esp32/uart connector circuit.png

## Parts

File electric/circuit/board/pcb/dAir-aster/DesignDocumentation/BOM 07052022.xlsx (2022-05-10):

Designator | Description | Comment | Quantity
DD3 | ADC MCP3421A2T-E/CH, 2.7-5.5V18-Bit, SOT23-6 |  | 1
DA3 | Battery charger BQ24075, VQFN_16 |  | 1
DA8 | Bus Transceiver SN74LVC1T45DBVR, SOT23-6 |  | 1
LS1 | Buzzer KPI-G1410 |  | 1
C26 | Cap electrolitic 2000µF 10V±10%, Ø13×20mm step 5mm |  | 1
C16 | Ceramic cap 0,1µF 10V ±10%, 0805 SMD, X5R or X7R |  | 1
C13 | Ceramic cap 0.1µF 10V ±10%, 0805 SMD, X5R or X7R |  | 1
C1, C2, C15, C17, C18, C23, C24 | Ceramic cap 0.1µF 16V ±10%, 0805 SMD, X5R or X7R, Ceramic cap 0.1µF 10V ±10%, 0805 SMD, X5R or X7R |  | 7
C19 | Ceramic cap 1µF 10V ±10%, 0805 SMD, X5R or X7R |  | 1
C5, C8, C9, C10, C11, C21 | Ceramic cap 1µF 16V ±10%, 0805 SMD, X5R or X7R, Ceramic cap 1µF 10V ±10%, 0805 SMD, X5R or X7R |  | 6
C25 | Ceramic cap 1mF 10V ±10%, 0805 SMD, X5R or X7R |  | 1
C12 | Ceramic cap 1nF 10V ±10%, 0805 SMD, X5R or X7R |  | 1
C4, C6 | Ceramic cap 4.7µF 16V ±10%, 0805 SMD, X5R or X7R |  | 2
C20 | Ceramic cap 22µF 10V ±10%, 0805 SMD, X5R or X7R |  | 1
DA1 | Charge controller DW01V, SOT23-6 |  | 1
XS1A | Connector USB Type-C-31-M-12 |  | 1
VD2 | Diod LL4148, SOD-80 |  | 1
DD2 | IC MPU SUPERVISORY MAX809RPR, 2.93V SOT23 |  | 1
DA4, DA5 | LDO XC6206P302PR 3V 0.2A, SOT89-3 |  | 2
DD1 | Microcontroller ESP-WROOM-32-8Mb, 38-Pin SMD |  | 1
DA2 | Mosfet dual N-chsnnel FS8205A TSSOP-8 |  | 1
F1 | Multifuse MF-MSMF050, 0.5 А, SMD 1812 |  | 1
VT1, VT2, VT3 | NPN-transistor BC847, SOT-23 |  | 3
DA6, DA7 | Oper. amplifiers AD8603AU, Rail-to-rail, TSOT-5 |  | 2
Bat1, Bat2 | Panasonic NCR18650 Li-ion 3200mAh or Liitokala NCR18650 Li-ion 3200mAh |  | 2
XP1 | Pin connector PLS-5 (DS1021-1×5), step 2.54mm |  | 1
VD1 | Rectifier diode LL4007, MELF/DO-213AB |  | 1
R4, R7, R10, R11, R27 | Res 1kOm±5%, SMD 0805 |  | 5
R25 | Res 1MOm±5%, SMD 0805 |  | 1
R6 | Res 2kOm±5%, SMD 0805 |  | 1
R2, R2.1 | Res 5.1kOm±5%, SMD 0805, Res 5.1Om±5%, SMD 0805 |  | 2
R5, R17, R18, R19, R20, R32 | Res 10kOm±5%, SMD 0805, Res 10lkOm±5%, SMD 0805 |  | 6
R8, R9, R23, R24, Rt1 | Res 47kOm±5%, SMD 0805 |  | 5
R3, R3.1 | Res 56kOm±5%, SMD 0805 |  | 2
R14, R29 | Res 100kOm±5%, SMD 0805 |  | 2
R15, R30 | Res 100Om±5%, SMD 0805 |  | 2
R28 | Res 120kOm±5%, SMD 0805 |  | 1
R26 | Res 150kOm±5%, SMD 0805 |  | 1
R1 | Res 300Om±5%, SMD 0805 |  | 1
R13 | Res 470kOm±5%, SMD 0805 |  | 1
R12, R21, R22, R31 | Res 470Om±5%, SMD 0805 |  | 4
XP2 | Module CJMCU-680 (BME680) |  | 1
V1_1 | Sensor ME2-CO |  | 1
HL1 | SMD LED GNL-1206SRC |  | 1
HL2 | SMD LED WS2812B |  | 1
HL3, HL4, HL5 | SMD LED WS2812B |  | 3
S1 | Tact switch KLS7-TS6604-7.0 or IT1102WB |  | 1
S2 | Tact switch KLS7-TS6606-8.0 or TS-A3PV, TC-0206, IT-1102HC, IT-1102NC |  | 1
S3 | Button switch 58LHTHRA |  | 1
C3 | Tantal chip cap 47µF 10V ±10%, type B |  | 1
C7, C14, C22 | Tantal chip cap 100µF 10V ±10%, type B, Tantal chip cap 100µF 16V ±10%, type B |  | 3
 | Battery clip CR123A (KLS5-54T). Manufacture "KLSelectronic" | Standard size 18650 | 4
 | Pin connector PLS-4 (DS1021-1×5), step 2.54mm | For sensor BME680 | 1

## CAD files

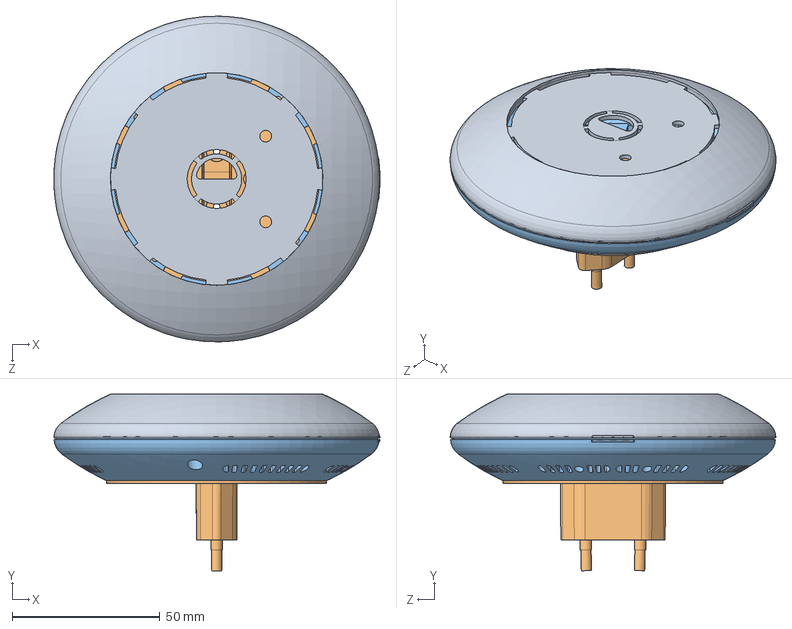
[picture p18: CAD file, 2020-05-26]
housing/enclosure/DAir-Clove/Model/Integration.SLDASM
110.3 x 59.7 x 110.1 mm
Верхняя крышка
Вилка
Нижняя крышка

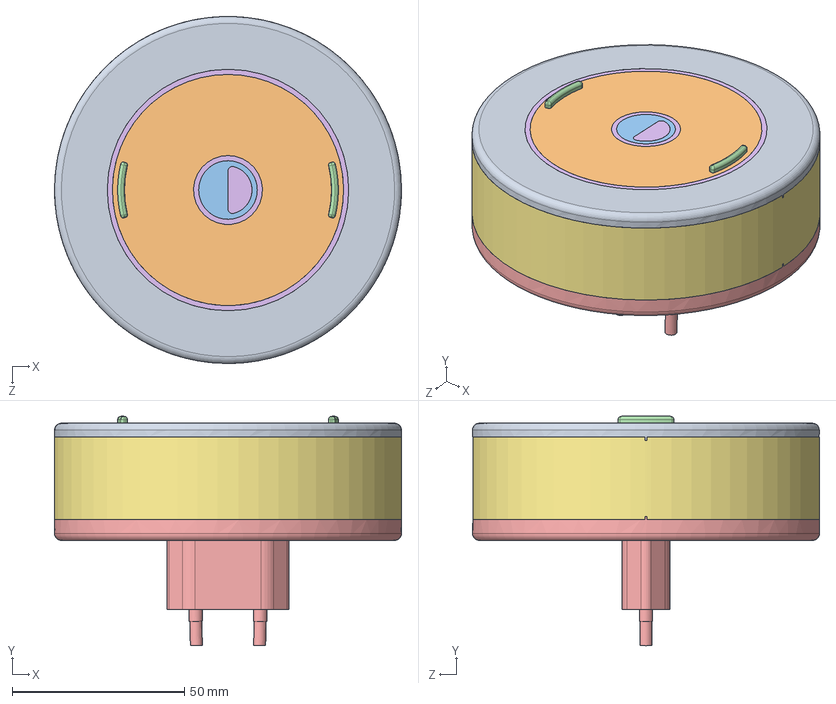
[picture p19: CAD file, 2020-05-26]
housing/enclosure/DAir-Peony/Models/Integration.SLDASM
100.6 x 66.5 x 100.6 mm
Верхняя крышка
Вставка_1
Вставка_2
Кнопка x 2
Нижняя крышка
Световод
Сетка

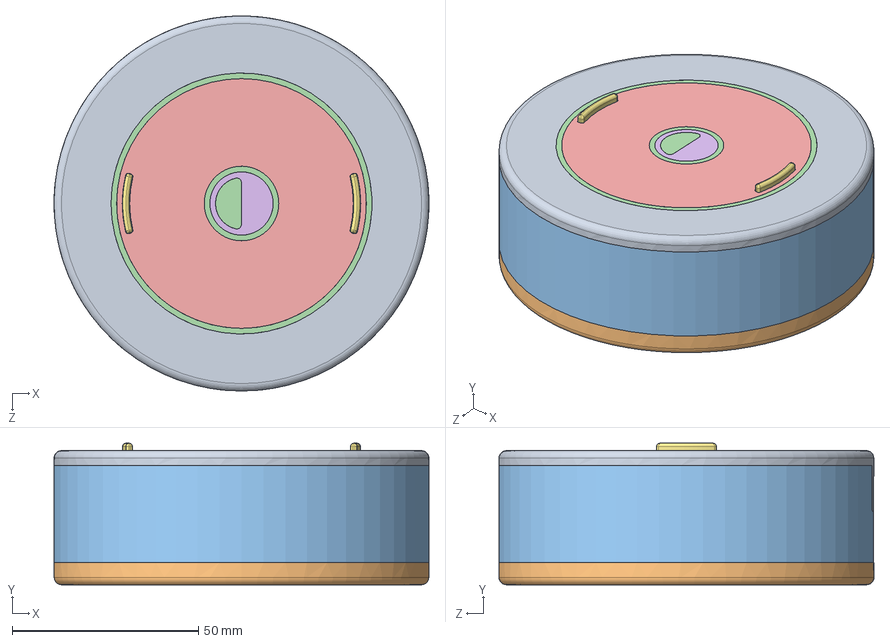
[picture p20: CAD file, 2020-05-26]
housing/enclosure/DAir-Rose/Models/Integration.SLDASM
100.6 x 38.0 x 100.6 mm
Верхняя крышка
Нижняя крышка(переносной)
Сетка
Световод
Вставка_1
Вставка_2
Кнопка x 2
Extruded-22 x 4
Extruded-23 x 12
Extruded-24 x 6
Extruded-25 x 20
Extruded-26 x 10
Extruded-27 x 4
Extruded-28
Extruded-29
Extruded-30
Extruded-31 x 2
User Library-esp-wroom-32-1
Extruded-32
User Library-WS2812B-3 x 5
User Library-WS2812B-4 x 5
User Library-WS2812B-5 x 5
Extruded-33
Extruded-34
Extruded-35
Extruded-36
Extruded-37 x 26
Extruded-38 x 13
Extruded-39 x 30
Extruded-40 x 15
Extruded-41
Extruded-42 x 3
Extruded-43 x 2
Pin-1 x 10
Insulator-1 x 2
Shielding-1 x 2
Board-Part-1-1

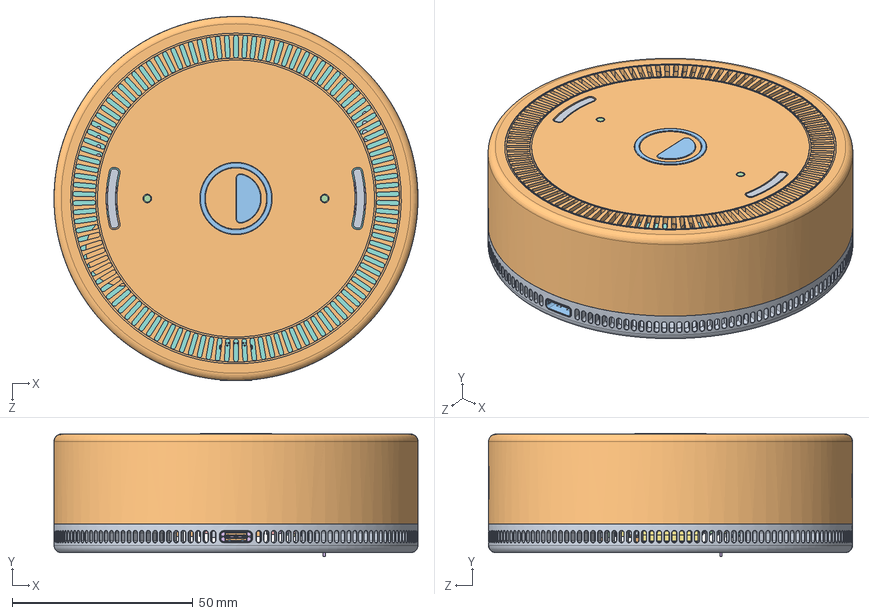
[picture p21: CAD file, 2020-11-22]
housing/enclosure/DAir-Aster/Model/Integration.SLDASM
100.6 x 34.1 x 100.6 mm
Cover
Enclosure
Logo
Lightguide x 2
Extruded x 18
Extruded-1 x 9
Extruded-2 x 5
Extruded-3 x 20
Extruded-4 x 10
Extruded-5
Extruded-6
Extruded-7 x 2
User Library-esp-wroom-32
Extruded-8
User Library-WS2812B x 2
User Library-WS2812B-1 x 2
User Library-WS2812B-2 x 2
Extruded-9
Extruded-10
Extruded-11
Extruded-12 x 16
Extruded-13 x 8
Extruded-14 x 48
Extruded-15 x 24
Extruded-16 x 3
Extruded-17 x 2
632723300011_Shielding_2 x 2
632723300011_Housing_Bottom3
632723300011_PIN7_Bottom_v3_mir
632723300011_PIN5_Bottom_v3_mir
632723300011_PIN2_Bottom_v3_mir
632723300011_PIN6_Bottom_v3_mir
632723300011_PIN4_Bottom_v3_mir
632723300011_PIN1_Bottom_v3_mir
632723300011_PIN2_Top_v3 x 8
632723300011_PIN7_Bottom_v3
632723300011_PIN6_Bottom_v3
632723300011_PIN5_Bottom_v3
632723300011_PIN4_Bottom_v3
632723300011_PIN2_Bottom_v3
632723300011_PIN1_Top_v3 x 4
632723300011_PIN1_Bottom_v3
632723300011_Housing_Bottom
632723300011_Shielding_1_v3
632723300011_Housing_TOP
632723300011_Shielding_3_v3
632723300011_Housing
Extruded-18
Board-Part-1
Flat_button_2.0х16.0mm x 2

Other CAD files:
housing/enclosure/DAir-Lily/Models/Model of Top PCB/Board-1.sldasm
housing/enclosure/DAir-Lily/Models/Model of Bottom PCB/C3.sldasm
housing/enclosure/DAir-Lily/Models/Model of Top PCB/S2.sldasm
housing/enclosure/DAir-Peony/Models/Model of PCB/R23-1.sldasm
housing/enclosure/DAir-Lily/Models/Model of Bottom PCB/D.sldasm
housing/enclosure/DAir-Rose/Models/Model of PCB/R13-1.sldasm
housing/enclosure/DAir-Clove/Model/Model of PCB/C5.sldasm
housing/enclosure/DAir-Lily/Models/Model of Bottom PCB/C21.sldasm
housing/enclosure/DAir-Peony/Models/Model of PCB/DA2-2.sldasm
housing/enclosure/DAir-Rose/Models/Model of PCB/C18-1.sldasm
housing/enclosure/DAir-Clove/Model/Model of PCB/DA6.sldasm
housing/enclosure/DAir-Lily/Models/Model of Top PCB/HL4.sldasm
housing/enclosure/DAir-Peony/Models/Model of PCB/HL7-1.sldasm
housing/enclosure/DAir-Lily/Models/Model of Bottom PCB/Board.sldasm
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

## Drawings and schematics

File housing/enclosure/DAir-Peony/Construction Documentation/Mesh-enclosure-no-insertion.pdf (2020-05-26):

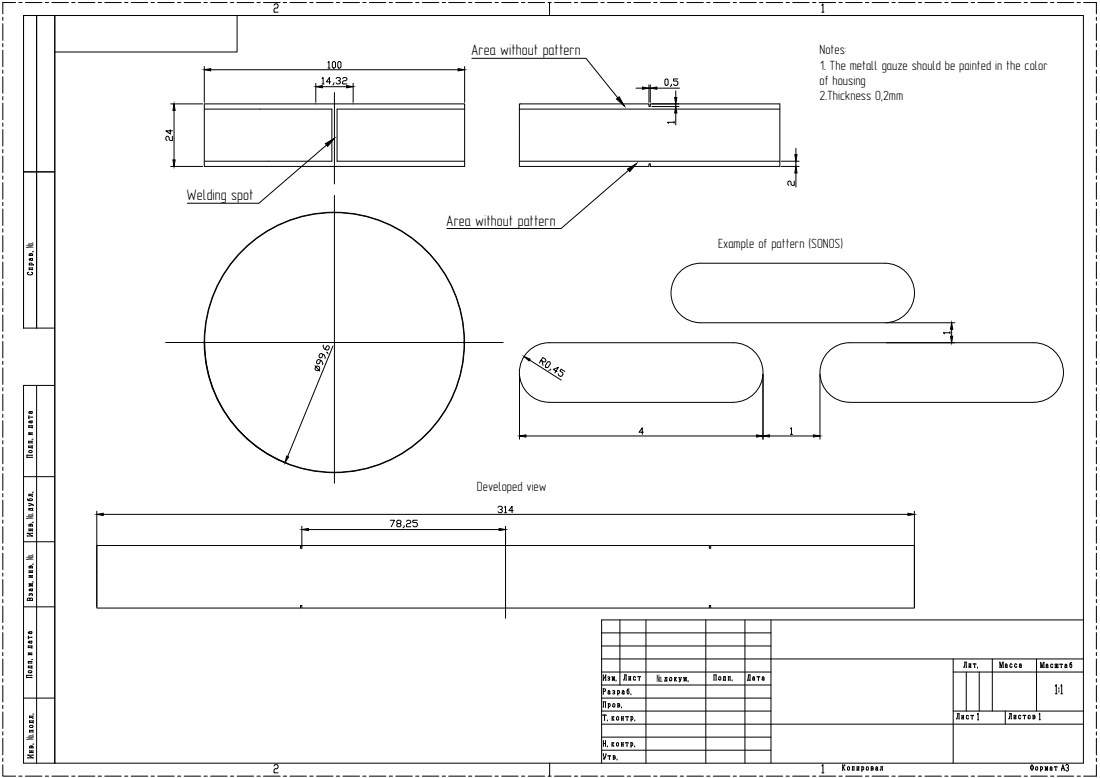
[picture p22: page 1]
Welding spot; Notes: 1. The metall gauze should be painted in the color of housing 2.Thickness 0,2mm Example of pattern (SONOS) Area without pattern Area without pattern Developed view

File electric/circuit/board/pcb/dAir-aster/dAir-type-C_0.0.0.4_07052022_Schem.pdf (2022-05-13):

# ESP-32Wroom Module Power Supply


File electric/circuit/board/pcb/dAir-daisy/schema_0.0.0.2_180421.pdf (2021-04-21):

Power Supply | ESP-32Wroom Module

# GND1

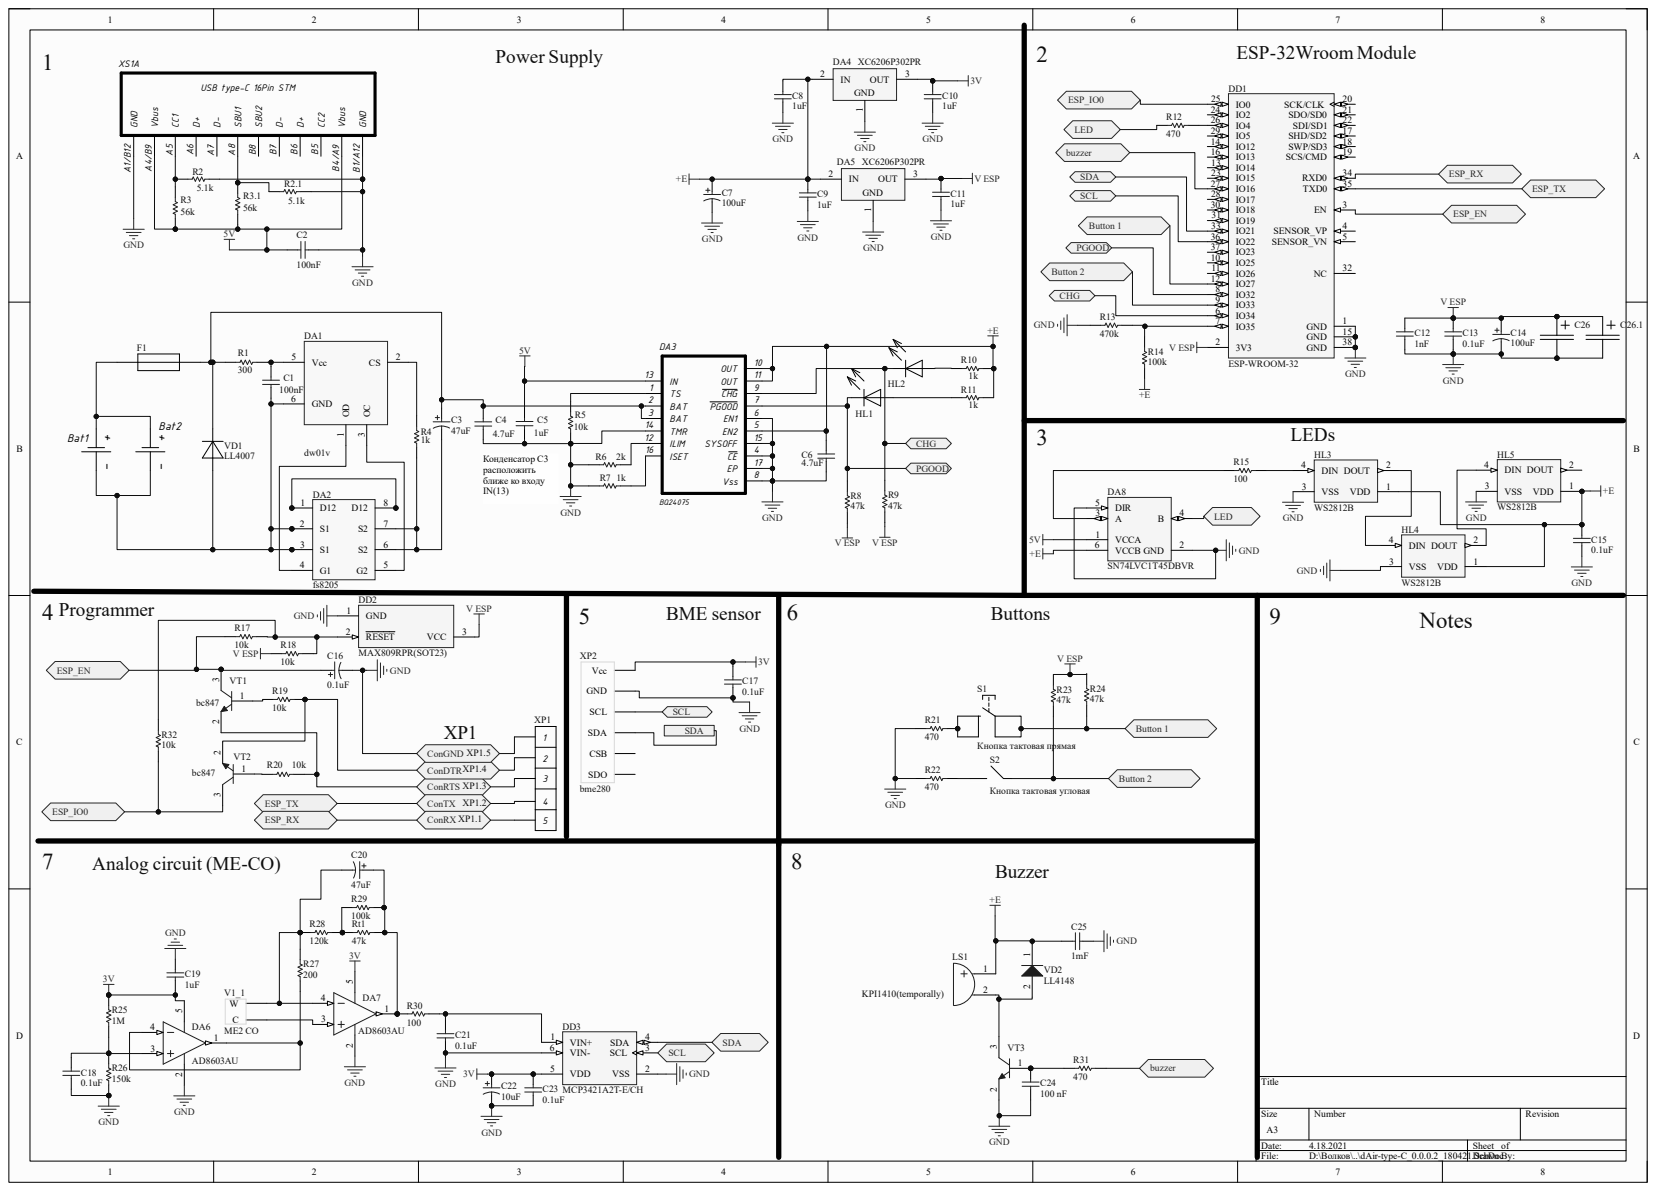
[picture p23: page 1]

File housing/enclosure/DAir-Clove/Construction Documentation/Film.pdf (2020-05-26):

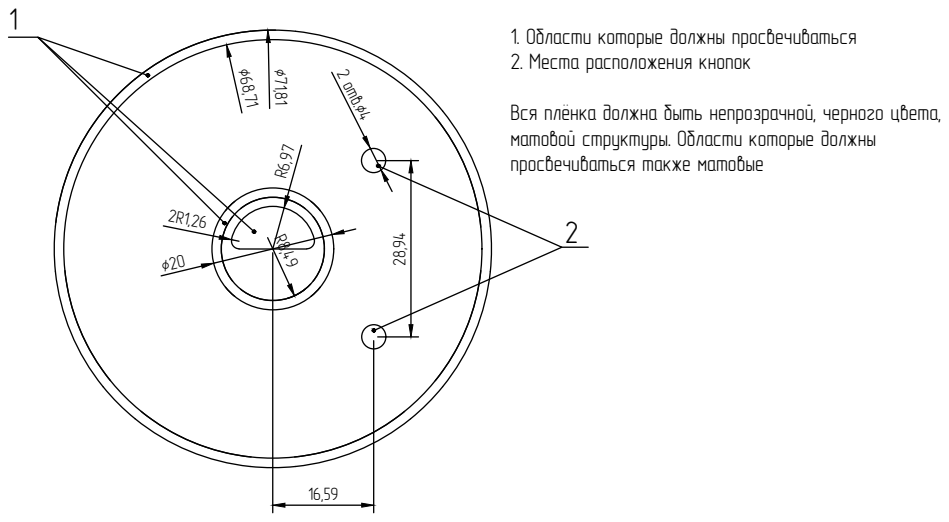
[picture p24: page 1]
2 отв.∅4

1. Области которые должны просвечиваться
2. Места расположения кнопок

Вся плёнка должна быть непрозрачной, черного цвета, матовой структуры. Области которые должны

просвечиваться также матовые

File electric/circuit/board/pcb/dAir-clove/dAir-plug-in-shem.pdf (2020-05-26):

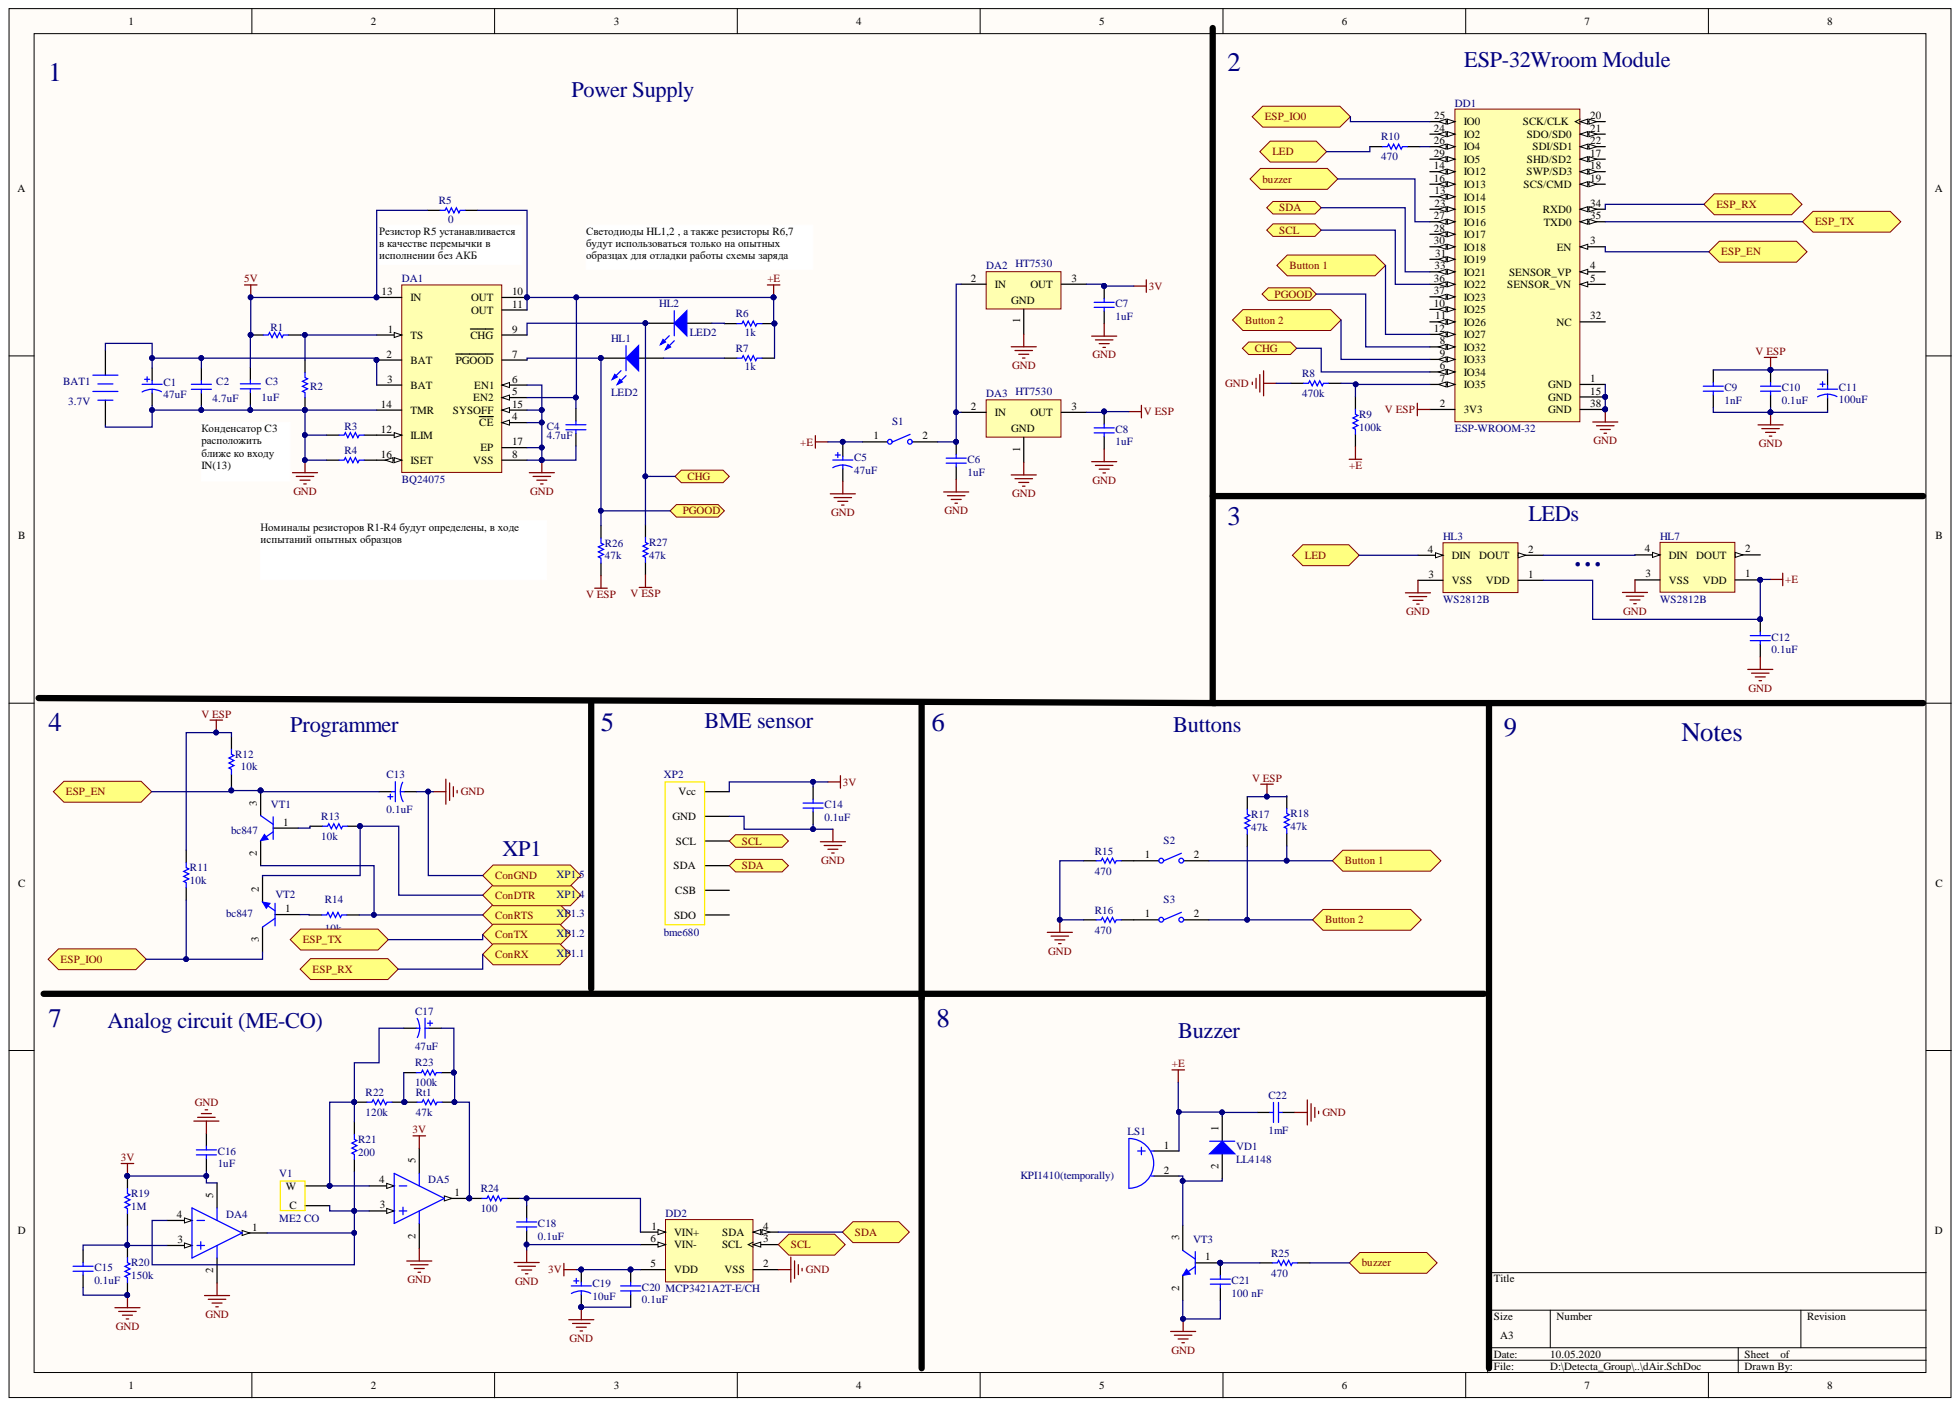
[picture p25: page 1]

Светодиоды HL1,2 , а также резисторы R6,7
будут использоваться только на опытных
образцах для отладки работы схемы заряда

Номиналы резисторов R1-R4 будут определены, в ходе
испытаний опытных образцов

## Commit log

2020-05-26 add electric to git
    [Korpus_V0_5_6.dwg, Upper_pcb_with_lcds_buttons_bme_CIRCULAR.pcbdoc, bottom_power_supply_pcb.pcbdoc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]
2020-05-26 add dAir-Clove v0.0.0.2 to electric
    [dAir-clove-0.0.0.1.PcbDoc, dAir-clove-0.0.0.2.PcbDoc, dAir-clove-controls-0.0.0.1.PcbDoc]
2020-05-26 add dAir-rose v1.0.0.0 to electric
    [dAir-rose-1.0.0.0.PcbDoc, dAir-rose.PrjPCB, dAir-usb-plug-in-compatible.SchDoc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]
2020-05-26 add housing folder
    [00007034.SLDASM, 00007734_Oberteil flach.sldprt, 00007735_Unterteil plan.sldprt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]
2020-05-26 add DAir-Lily v0.1.0 to housing
2020-05-26 add DAir-Peony v0.2.1 to housing
    [Base-plug.SLDASM, Base.SLDPRT, Base.STL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]
2020-05-26 add DAir-Peony v0.2.2 to housing
    [Base-plug.SLDASM, Base.SLDPRT, Base.STL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]
2020-05-26 add DAir-Lily v0.2.0 to housing
    [Button.SLDPRT, Button.STL, Lighted panel.STL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]
2020-05-26 add DAir-Rose v0.2.1 to housing
    [Base-noPlug.SLDPRT, Base.SLDPRT, Base.STL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]
2020-05-26 add DAir-Rose v0.2.2 to housing
    [Base-noPlug.SLDPRT, Base.STL, Cover.SLDPRT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]
2020-05-26 add DAir-Rose v0.3.3 to housing
    [Base-noPlug.SLDPRT, Cover.SLDPRT, Edge-lighted panel.STL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]
2020-06-13 add DAir-ASTER v0.2.4
    [bottom.STL, top.STL, Кнопка_2.6.STL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]
2020-06-15 English translation DAir-ASTER models
    [Button_2.6.STL, Button_2.6мм.SLDPRT, Button_2.8.STL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]
2020-06-21 112 - fix mm
    [Button_2.6mm.SLDPRT, Button_2.8mm.SLDPRT, Button_3.STL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]
2020-08-24 136 - Aster PCB fixes and improvements * Increased version from 0.0.0.1 to 0.0.0.2 * added open GND pads for oscilloscope * fixed some designators placing * added SN74LVC1T45 for LEDs * added steel h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
    [dAir-aster-0.0.0.1.PcbDoc, dAir-aster-0_0_0_2.PcbDoc, dAir-aster.PrjPCB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]
2020-09-24 164 - Aster housing fix
    [Button_2.0x16.0mm.SLDPRT, Button_2.0x16.STL, Button_2.6mm.SLDPRT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]
2020-09-29 fix model location
    [Button_2.0x16.0mm.SLDPRT, Button_2.0x16.STL, Button_2.6.STL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]
2020-10-04 164 - fix button
    [Button_2.0x16.0mm.SLDPRT, Button_2.0x16.STL, Button_2.6.STL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]
2020-11-22 190 - upgrade housing to v 0.4.5 * fix button * fix lightguide *fix prop MCO2 * etc
    [Button_2.0x16.0mm.SLDPRT, Button_2.0x16.STL, Cover.SLDPRT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]
2021-04-14 add dAir-daisy 0.0.0.2
    [dAir-aster_0.0.0.2.PrjPCB, dAir-type-C_0.0.0.2.SchDoc, dAir.SchLib]
2021-04-21 update d-air-daisy before producation
    [dAir-aster_0.0.0.2.PrjPCB, dAir-aster_0.0.0.2_180421.PrjPCB, dAir-type-C_0.0.0.2.SchDoc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]
2022-05-10 Move dAir-Aster
    [Button_2.0x16.0mm.SLDPRT, Button_2.0x16.STL, Cover.SLDPRT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]
2022-05-10 Add dAir Aster 0.0.0.4 board and circuit
    [BOM_07052022.xlsx, Design_documentation_07052022_AutoCAD_2018.dwg, Korpus_V0_5_6.dwg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]
2022-05-13 Small fixes in documentation for 0.0.0.4
    [BOM 07052022.xlsx, Design documentation 07052022_AutoCAD_2019.dwg, Design_documentation_07052022_AutoCAD_2018.dwg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]
